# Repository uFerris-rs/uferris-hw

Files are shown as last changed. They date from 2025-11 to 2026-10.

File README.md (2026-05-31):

# 🦀 uFerris Embedded Rust Learner Board

<div align="center">
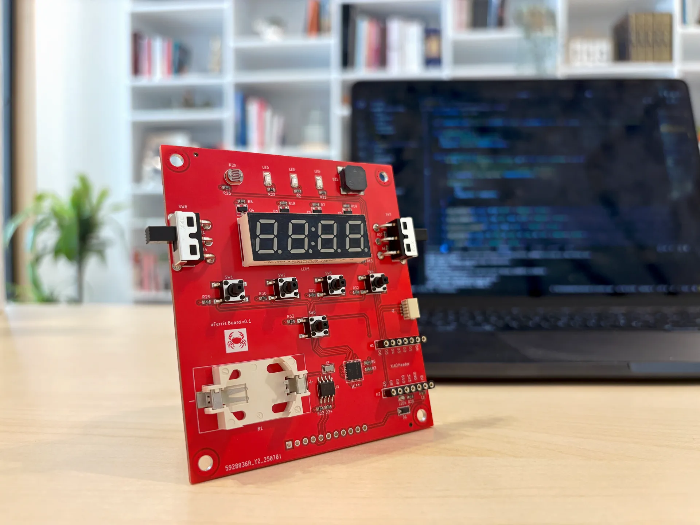
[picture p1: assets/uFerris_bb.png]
  
</div>
<br>

**uFerris** is a versatile, all-in-one learner board designed to:

- Support multiple controllers on a single reference platform.
- Enable programming of standard peripherals (GPIO, Timers/Counters, Analog, PWM, Serial Comms).
- Allow learners to build a complete embedded product replica.
- Serve as a centralized reference for Rust embedded beginners.

## 📦 Purchase

For pre-built hardware, uFerris can be acquired from [The Embedded Rustacean Store](https://shop.theembeddedrustacean.com/).

## 🧱 Board Variants

### Megalops Baseboard
The baseboard is equipped with components that let you practice and apply your skills across all standard peripherals. The baseboard also features a SeeedStudio XIAO platform header, giving the flexibility to work with a wide range of controllers.

<div align="center">
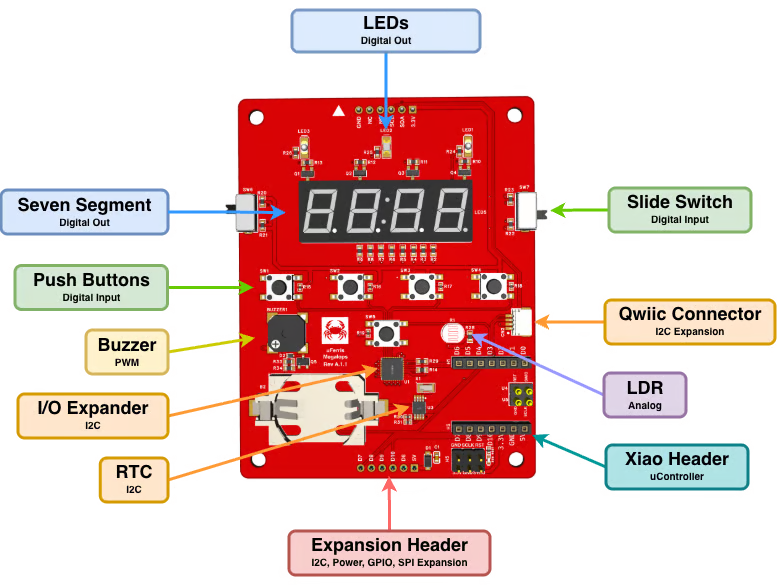
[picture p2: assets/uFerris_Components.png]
  
</div>
<br>

<div align="center">
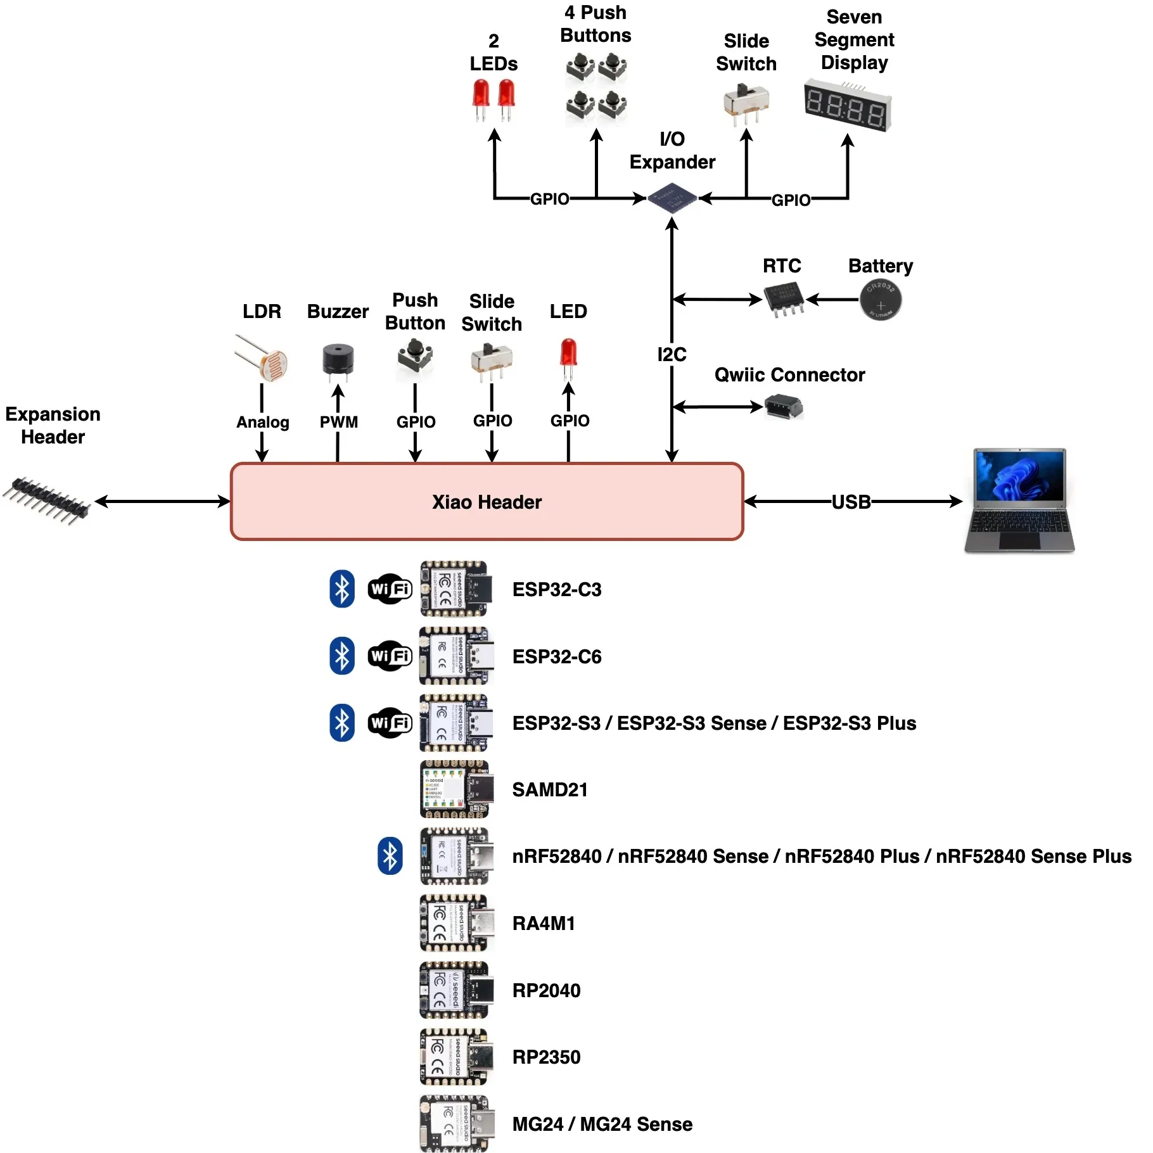
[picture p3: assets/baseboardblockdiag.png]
  
</div>
<br>

### Megalops Power Expansion Board

The Power Expansion Board lets the uFerris baseboard run independently of USB power. It features a 2×AAA battery holder with a current measurement circuit, making it easy to measure current consumption for your projects. It also includes an SD card holder—perfect for learning SPI and storing or logging data directly from your applications.

<div align="center">
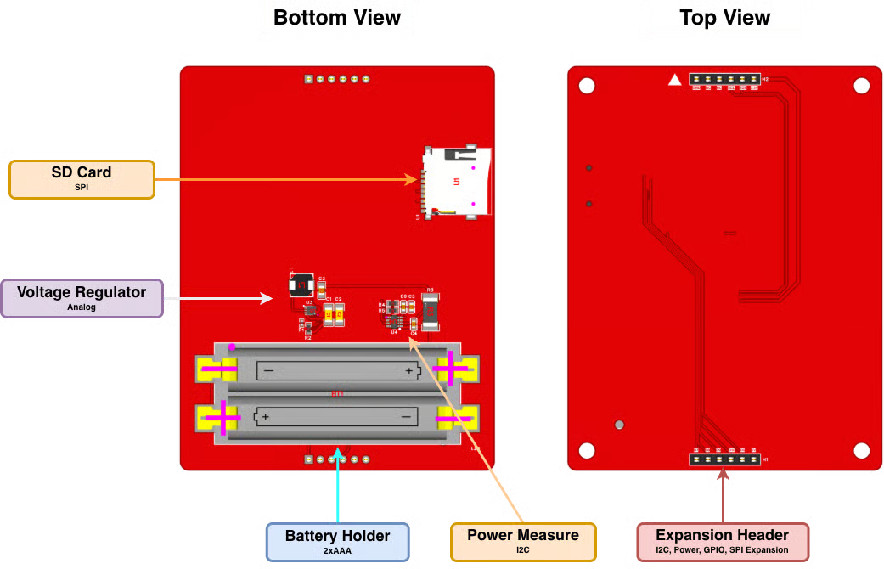
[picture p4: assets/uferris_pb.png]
  
</div>
<br>

## 📁 Repository Structure
- [`boards/`](boards/) → Hardware designs (schematic, PCB, BOM)
- [`docs/`](docs/) → Documentation and certifications
- [`firmware/`](firmware/) → Example Rust firmware projects
- [`assets/`](assets/) → Images and media assets

## 🏁 Getting Started
To get started, refer to the [getting-started.md](https://github.com/uFerris-rs/uferris-hw/blob/main/docs/getting-started.md) document.

## 📄 Certifications

uFerris is certified open source hardware by the Open Source Hardware Association.

<div align="center">
<a href="https://certification.oshwa.org/jo000001.html">
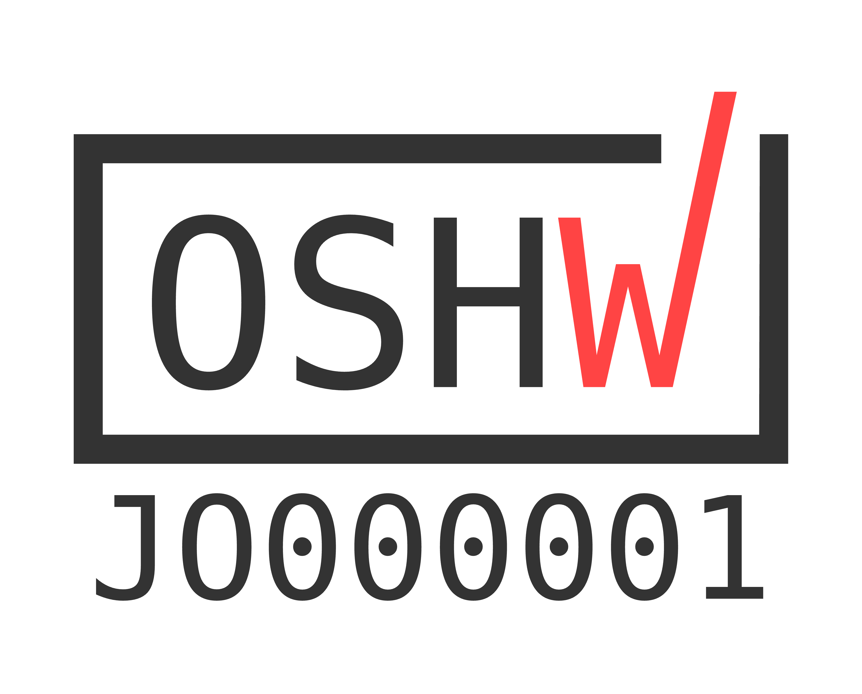
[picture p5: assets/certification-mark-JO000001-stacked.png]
OSHW Certified JO000001
  
</a>
</div>

- **OSHWA UID:** [JO000001](https://certification.oshwa.org/jo000001.html)
- **Certification Date:** May 8, 2026
- **Hardware License:** CC-BY-SA-4.0
- **Software License:** MIT

uFerris is the first OSHWA-certified project from Jordan.

See [`docs/`](docs/) for more compliance details.

## 📜 License

All uFerris boards and their derivatives are licensed
under the Creative Commons Attribution-ShareAlike 4.0 International License (CC BY-SA 4.0).

All software and firmware examples are licensed under the MIT License.

## 🌐 Learn More

To stay updated and learn more about uFerris, subscribe to The Embedded Rustacean newsletter: https://www.theembeddedrustacean.com/subscribe 

---

Developed and maintained by **The Embedded Rustacean**  🦀

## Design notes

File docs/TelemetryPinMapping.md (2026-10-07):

# uFerris Megalops Telemetry Board Pin Mapping

The telemetry board (Rev A.0.0) carries an RP2040 that reads and drives the uFerris baseboard lines. It mates with the baseboard's Telemetry Headers (U2, U6, U7) and Expansion Headers (H3, H4).

`Signal` columns use the baseboard net names (see `uFerrisPinMapping.md`), so names are identical across both boards. Where the telemetry schematic uses a different net name, it is shown in `Telemetry Net`.

Eight baseboard signals share four RP2040 pins each through two TMUX1574 2:1 muxes (U4, U9), switched by `MODESEL` (GPIO0). With `MODESEL = 0` the RP2040 sees the XIAO-side signals; with `MODESEL = 1` it sees the 7-segment signals. Both mux enables (EN#) are tied to GND.

## RP2040 GPIO Map

| RP2040 GPIO | RP2040 Pin | Function | Telemetry Net | Path | Signal (MODESEL=0) | Signal (MODESEL=1) | Telemetry Header Pin | Baseboard Header Pin | Baseboard Source | Notes |
|:---|:---|:---|:---|:---|:---|:---|:---|:---|:---|:---|
| GPIO0 | 2 | GPIO0 | MODESEL | Mux select | - | - | - | - | - | Drives SEL on U4 and U9. 0 = XIAO-side signals, 1 = 7-segment signals |
| GPIO1 | 3 | GPIO1 | XIAOMOSI/E | Mux U9 D1 | XIAOMOSI | E | H2-3 / H5-8 | H3-3 / U6-6 | Xiao D10 / Expander P24 | |
| GPIO2 | 4 | GPIO2 | SWCLK_XIAO | Direct | SWCLK | SWCLK | H5-5 | U6-1 | Xiao SWD pad (pogo) | Net name differs from baseboard (SWCLK) |
| GPIO3 | 5 | GPIO3 | SWIO_XIAO | Direct | SWIO | SWIO | H5-3 | U6-5 | Xiao SWD pad (pogo) | Net name differs from baseboard (SWIO) |
| GPIO4 | 6 | GPIO4 | XIAORX/B | Mux U9 D2 | XIAORX | B | H2-6 / H5-2 | H3-6 / U6-7 | Xiao D7 / Expander P21 | |
| GPIO5 | 7 | GPIO5 | XIAOMISO/DP | Mux U9 D3 | XIAOMISO | DP | H2-4 / H6-1 | H3-4 / U7-9 | Xiao D9 / Expander P26 | |
| GPIO6 | 8 | GPIO6 | XIAOTX/G | Mux U9 D4 | XIAOTX | G | H2-2 / H6-9 | H3-2 / U7-8 | Xiao D6 / Expander P27 | |
| GPIO7 | 9 | GPIO7 | BUZZERWIRE/A  | Mux U4 D1 | BUZZERWIRE | A | H5-6 / H5-1 | U6-2 / U6-9 | Xiao D2/A2 / Expander P20 | |
| GPIO8 | 11 | GPIO8 | LED1WIRE/F | Mux U4 D2 | LED1WIRE | F | H6-2 / H5-7 | U7-7 / U6-4 | Xiao D1/A1 / Expander P25 | |
| GPIO9 | 12 | GPIO9 | SW5WIRE/D | Mux U4 D3 | SW5WIRE | D | H6-4 / H5-9 | U7-3 / U6-8 | Xiao D3 / Expander P23 | |
| GPIO10 | 13 | GPIO10 | XIAOSCL/C | Mux U4 D4 | XIAOSCL | C | H2-5 / H5-10 | H3-5 / U6-10 | Xiao D8 / Expander P22 | |
| GPIO11 | 14 | GPIO11 | RST_XIAO | Direct | RST | RST | H5-4 | U6-3 | Xiao SWD pad (pogo) | Net name differs from baseboard (RST) |
| GPIO12 | 15 | GPIO12 | SCL | Direct | SCL | SCL | H3-3 | H4-3 | Xiao D5 | |
| GPIO13 | 16 | GPIO13 | SDA | Direct | SDA | SDA | H3-2 | H4-2 | Xiao D4 | |
| GPIO14 | 17 | GPIO14 | SW1WIRE | Direct | SW1WIRE | SW1WIRE | H4-2 | U2-7 | Expander P07 | |
| GPIO15 | 18 | GPIO15 | SW2WIRE | Direct | SW2WIRE | SW2WIRE | H6-10 | U7-10 | Expander P06 | |
| GPIO16 | 27 | GPIO16 | SW3WIRE | Direct | SW3WIRE | SW3WIRE | H6-8 | U7-6 | Expander P05 | |
| GPIO17 | 28 | GPIO17 | SW4WIRE | Direct | SW4WIRE | SW4WIRE | H6-5 | U7-1 | Expander P04 | |
| GPIO18 | 29 | GPIO18 | LSWITCH | Direct | LSWITCH | LSWITCH | H4-5 | U2-1 | Expander P16 | |
| GPIO19 | 30 | GPIO19 | RSWITCH | Direct | RSWITCH | RSWITCH | H6-6 | U7-2 | Expander P01 | |
| GPIO20 | 31 | GPIO20 | DIGIT1 | Direct | DIGIT1 | DIGIT1 | H4-3 | U2-5 | Expander P10 | |
| GPIO21 | 32 | GPIO21 | DIGIT2 | Direct | DIGIT2 | DIGIT2 | H4-10 | U2-10 | Expander P11 | |
| GPIO22 | 34 | GPIO22 | DIGIT3 | Direct | DIGIT3 | DIGIT3 | H4-9 | U2-8 | Expander P12 | |
| GPIO23 | 35 | GPIO23 | DIGIT4 | Direct | DIGIT4 | DIGIT4 | H4-7 | U2-4 | Expander P13 | |
| GPIO24 | 36 | GPIO24 | LED2WIRE | Direct | LED2WIRE | LED2WIRE | H4-8 | U2-6 | Expander P14 | |
| GPIO25 | 37 | GPIO25 | LED3WIRE | Direct | LED3WIRE | LED3WIRE | H4-6 | U2-2 | Expander P15 | |
| GPIO26 | 38 | GPIO26 / ADC0 | LDRWIREBUF | Buffer U5 (MCP6002 follower) | LDRWIRE | LDRWIRE | H6-3 | U7-5 | Xiao D0/A0 | Analog: unity-gain buffered into ADC |
| GPIO27 | 39 | GPIO27 / ADC1 | XIAO3V3BUF | Buffer U5 (MCP6002 follower) | VCC | VCC | H3-1 | H4-1 | Baseboard 3V3 | Analog: unity-gain buffered into ADC. Net name differs from baseboard (VCC) |
| GPIO28 | 40 | GPIO28 / ADC2 | NC | - | - | - | - | - | - | Unused |
| GPIO29 | 41 | GPIO29 / ADC3 | NC | - | - | - | - | - | - | Unused |

## Header Mating

The 2×5 headers use different pin numbering on each board: the baseboard numbers odd/even across the rows, while the telemetry board numbers 1–5 down one column and 6–10 back up the other. The table gives the pin-to-pin correspondence, checked net-by-net against both netlists.

| Telemetry Header | Pin | Telemetry Net | Mates With (Baseboard) | Baseboard Signal (Net) |
|:---|:----|:---|:---|:---|
| H4 | 1 | NC | U2-9 | NC |
| H4 | 2 | SW1WIRE | U2-7 | SW1WIRE |
| H4 | 3 | DIGIT1 | U2-5 | DIGIT1 |
| H4 | 4 | NC | U2-3 | NC |
| H4 | 5 | LSWITCH | U2-1 | LSWITCH |
| H4 | 6 | LED3WIRE | U2-2 | LED3WIRE |
| H4 | 7 | DIGIT4 | U2-4 | DIGIT4 |
| H4 | 8 | LED2WIRE | U2-6 | LED2WIRE |
| H4 | 9 | DIGIT3 | U2-8 | DIGIT3 |
| H4 | 10  | DIGIT2 | U2-10 | DIGIT2 |
| H5 | 1 | A | U6-9 | A |
| H5 | 2 | B | U6-7 | B |
| H5 | 3 | SWIO_XIAO | U6-5 | SWIO |
| H5 | 4 | RST_XIAO | U6-3 | RST |
| H5 | 5 | SWCLK_XIAO | U6-1 | SWCLK |
| H5 | 6 | BUZZERWIRE | U6-2 | BUZZERWIRE |
| H5 | 7 | F | U6-4 | F |
| H5 | 8 | E | U6-6 | E |
| H5 | 9 | D | U6-8 | D |
| H5 | 10  | C | U6-10 | C |
| H6 | 1 | DP | U7-9 | DP |
| H6 | 2 | LED1WIRE | U7-7 | LED1WIRE |
| H6 | 3 | LDRWIRE | U7-5 | LDRWIRE |
| H6 | 4 | SW5WIRE | U7-3 | SW5WIRE |
| H6 | 5 | SW4WIRE | U7-1 | SW4WIRE |
| H6 | 6 | RSWITCH | U7-2 | RSWITCH |
| H6 | 7 | NC | U7-4 | NC |
| H6 | 8 | SW3WIRE | U7-6 | SW3WIRE |
| H6 | 9 | G | U7-8 | G |
| H6 | 10  | SW2WIRE | U7-10 | SW2WIRE |
| H2 | 1 | NC | H3-1 | +5V |
| H2 | 2 | XIAOTX | H3-2 | XIAOTX |
| H2 | 3 | XIAOMOSI | H3-3 | XIAOMOSI |
| H2 | 4 | XIAOMISO | H3-4 | XIAOMISO |
| H2 | 5 | XIAOSCL | H3-5 | XIAOSCL |
| H2 | 6 | XIAORX | H3-6 | XIAORX |
| H3 | 1 | XIAO3V3 | H4-1 | VCC |
| H3 | 2 | SDA | H4-2 | SDA |
| H3 | 3 | SCL | H4-3 | SCL |
| H3 | 4 | NC | H4-4 | NC |
| H3 | 5 | NC | H4-5 | NC |
| H3 | 6 | GND | H4-6 | GND |

## Other Connectors

| Connector | Pin | Net | Function |
|:---|:----|:---|:---|
| H1 (SWD, RP2040 debug) | 1 | VCC | Telemetry 3V3 |
| H1 (SWD, RP2040 debug) | 2 | SWCLK | RP2040 SWCLK (pin 24) |
| H1 (SWD, RP2040 debug) | 3 | SWD | RP2040 SWDIO (pin 25) |
| H1 (SWD, RP2040 debug) | 4 | GND | - |
| SW1 | - | RUN | RP2040 RUN (pin 26), reset button |
| SW3 | - | QSPI_SS | BOOTSEL button (via R3 1k) |
| USB1 | - | USB_D+ / USB_D- | RP2040 USB_DP/DM (pins 47/46) via 27Ω |
| USB1 | - | VUSB | AMS1117-3.3 input → telemetry VCC |
| LED1 | - | VCC | Power LED (470Ω) |

## Notes
- **Hardware peripherals don't line up with the routed pins; plan on PIO for bus capture.**
  - I²C: SCL is on GPIO12 and SDA on GPIO13. In the RP2040's fixed I²C mapping GPIO12 is I2C0 SDA and GPIO13 is I2C0 SCL, so the pair is swapped for the hardware block.
  - UART: XIAOTX lands on GPIO6, which has no UART RX function. XIAORX is on GPIO4 (UART1 TX), so the RP2040 can drive the XIAO's RX with hardware UART but can't receive the XIAO's TX that way.
  - SPI: XIAOMOSI (GPIO1), XIAOMISO (GPIO5) and XIAOSCL (GPIO10) don't form a hardware SPI set.
- XIAO serial/SPI lines and the 7-segment lines are never visible at the same time; see `MODESEL`.
- `XIAO3V3` is the baseboard `VCC` rail (H4-1), buffered into ADC1 for supply monitoring. The telemetry board's own `VCC` is a separate 3V3 from USB; the boards share only GND (H4-6).
- Baseboard H3-1 (+5V) is not connected on the telemetry side.
- GPIO28 and GPIO29 are unused.
- The telemetry net names `SWCLK` and `SWD` belong to the RP2040's own debug port (H1), **not** the baseboard XIAO SWD lines (`SWCLK_XIAO`, `SWIO_XIAO`, `RST_XIAO`).

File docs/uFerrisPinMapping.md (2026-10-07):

# uFerris Pin Mapping

The table below provides a comprehensive mapping of the various components and their connections to the Xiao, I/O Expander, Expansion Headers H3/H4, Telemetry Headers U2/U6/U7, the SWD debug header H5 and pogo pins U4/U5, and the ESP32-C3 and ESP32-C6 pins.

Note that the enclosure labels are in refrence to the 3D printed enclosure for the uFerris alarm clock project.

`Signal (Net)` is the schematic net name and is the canonical signal name shared with the telemetry extension board. Header pins are written as `<RefDes>-<Pin>`.

| Enclosure Label | Component Connection | Signal (Net) | Xiao Pin | I/O Expander Pin | Header H3 Pin | Header H4 Pin | Telemetry Header Pin | Debug H5 Pin | SWD Pogo Pin | Direction | ESP32-C3 Pin | ESP32-C6 Pin |
|:---|:---|:---|:---|:---|:---|:---|:---|:---|:---|:---|:---|:---|
| Alarm | LED 1 | LED1WIRE | D1/A1 | - | - | - | U7-7 | - | - | Output | GPIO3 | GPIO1 |
| LED | LED 2 | LED2WIRE | - | P14 | - | - | U2-6 | - | - | Output | - | - |
| PM | LED 3 | LED3WIRE | - | P15 | - | - | U2-2 | - | - | Output | - | - |
| - | Buzzer | BUZZERWIRE | D2/A2 | - | - | - | U6-2 | - | - | Output | GPIO4 | GPIO2 |
| Hour | SW1 | SW1WIRE | - | P07 | - | - | U2-7 | - | - | Input | - | - |
| Minute | SW2 | SW2WIRE | - | P06 | - | - | U7-10 | - | - | Input | - | - |
| Time | SW3 | SW3WIRE | - | P05 | - | - | U7-6 | - | - | Input | - | - |
| Alarm | SW4 | SW4WIRE | - | P04 | - | - | U7-1 | - | - | Input | - | - |
| Snooze | SW5 | SW5WIRE | D3 | - | - | - | U7-3 | - | - | Input | GPIO5 | GPIO21 |
| 12/24 | SW6 | LSWITCH | - | P16 | - | - | U2-1 | - | - | Input | - | - |
| On/Off | SW7 | RSWITCH | - | P01 | - | - | U7-2 | - | - | Input | - | - |
| - | SDA | SDA | D4 | - | - | P2 | - | - | - | Comms | GPIO6 | GPIO22 |
| - | SCL | SCL | D5 | - | - | P3 | - | - | - | Comms | GPIO7 | GPIO23 |
| - | LDR | LDRWIRE | D0/A0 | - | - | - | U7-5 | - | - | Analog | GPIO2 | GPIO0 |
| - | Digit 1 | DIGIT1 | - | P10 | - | - | U2-5 | - | - | Output | - | - |
| - | Digit 2 | DIGIT2 | - | P11 | - | - | U2-10 | - | - | Output | - | - |
| - | Digit 3 | DIGIT3 | - | P12 | - | - | U2-8 | - | - | Output | - | - |
| - | Digit 4 | DIGIT4 | - | P13 | - | - | U2-4 | - | - | Output | - | - |
| - | Seg A | A | - | P20 | - | - | U6-9 | - | - | Output | - | - |
| - | Seg B | B | - | P21 | - | - | U6-7 | - | - | Output | - | - |
| - | Seg C | C | - | P22 | - | - | U6-10 | - | - | Output | - | - |
| - | Seg D | D | - | P23 | - | - | U6-8 | - | - | Output | - | - |
| - | Seg E | E | - | P24 | - | - | U6-6 | - | - | Output | - | - |
| - | Seg F | F | - | P25 | - | - | U6-4 | - | - | Output | - | - |
| - | Seg G | G | - | P27 | - | - | U7-8 | - | - | Output | - | - |
| - | DP | DP | - | P26 | - | - | U7-9 | - | - | Output | - | - |
| - | XiaoTx | XIAOTX | D6 | nINT | P2 | - | - | - | - | - | GPIO21 | GPIO16 |
| - | XiaoMosi | XIAOMOSI | D10 | - | P3 | - | - | - | - | - | GPIO10 | GPIO18 |
| - | XiaoMiso | XIAOMISO | D9 | - | P4 | - | - | - | - | - | GPIO9 | GPIO20 |
| - | XiaoScl | XIAOSCL | D8 | - | P5 | - | - | - | - | - | GPIO8 | GPIO19 |
| - | XiaoRx | XIAORX | D7 | - | P6 | - | - | - | - | - | GPIO20 | GPIO17 |
| - | SWCLK | SWCLK | SWD pad (pogo) | - | - | - | U6-1 | H5-4 | U5-2 | Debug | - | - |
| - | SWDIO | SWIO | SWD pad (pogo) | - | - | - | U6-5 | H5-5 | U4-2 | Debug | - | - |
| - | RST | RST | SWD pad (pogo) | - | - | - | U6-3 | H5-6 | U4-1 | Debug | - | - |

## Header Pinouts

Pin-ordered view of the telemetry and debug headers (schematic Rev A.2.0). `NC` = not connected.

### Telemetry Headers (U2, U6, U7 — PZ254-2-05-S, 2×5, 2.54 mm)

**U2**

| Pin | Signal (Net) | Component | Source |
|:----|:---|:---|:---|
| 1 | LSWITCH | SW6 | Expander P16 |
| 2 | LED3WIRE | LED 3 | Expander P15 |
| 3 | NC | - | - |
| 4 | DIGIT4 | Digit 4 | Expander P13 |
| 5 | DIGIT1 | Digit 1 | Expander P10 |
| 6 | LED2WIRE | LED 2 | Expander P14 |
| 7 | SW1WIRE | SW1 | Expander P07 |
| 8 | DIGIT3 | Digit 3 | Expander P12 |
| 9 | NC | - | - |
| 10  | DIGIT2 | Digit 2 | Expander P11 |

**U6**

| Pin | Signal (Net) | Component | Source |
|:----|:---|:---|:---|
| 1 | SWCLK | SWCLK | Xiao SWD pad (pogo) |
| 2 | BUZZERWIRE | Buzzer | Xiao D2/A2 |
| 3 | RST | RST | Xiao SWD pad (pogo) |
| 4 | F | Seg F | Expander P25 |
| 5 | SWIO | SWDIO | Xiao SWD pad (pogo) |
| 6 | E | Seg E | Expander P24 |
| 7 | B | Seg B | Expander P21 |
| 8 | D | Seg D | Expander P23 |
| 9 | A | Seg A | Expander P20 |
| 10  | C | Seg C | Expander P22 |

**U7**

| Pin | Signal (Net) | Component | Source |
|:----|:---|:---|:---|
| 1 | SW4WIRE | SW4 | Expander P04 |
| 2 | RSWITCH | SW7 | Expander P01 |
| 3 | SW5WIRE | SW5 | Xiao D3 |
| 4 | NC | - | - |
| 5 | LDRWIRE | LDR | Xiao D0/A0 |
| 6 | SW3WIRE | SW3 | Expander P05 |
| 7 | LED1WIRE | LED 1 | Xiao D1/A1 |
| 8 | G | Seg G | Expander P27 |
| 9 | DP | DP | Expander P26 |
| 10  | SW2WIRE | SW2 | Expander P06 |

### SWD Debug Header (H5 — PH2.54-2X3P, 2×3, 2.54 mm)

**H5**

| Pin | Signal (Net) | Component | Source |
|:----|:---|:---|:---|
| 1 | VCC | Power | - |
| 2 | GND | Power | - |
| 3 | GND | Power | - |
| 4 | SWCLK | SWCLK | Xiao SWD pad (pogo) |
| 5 | SWIO | SWDIO | Xiao SWD pad (pogo) |
| 6 | RST | RST | Xiao SWD pad (pogo) |

### SWD Pogo Pins (U4, U5 — 2-pin pogo, 2.50 mm)
These contact the SWD pads on the underside of XIAO variants that expose them.

**U4**

| Pin | Signal (Net) | Component | Source |
|:----|:---|:---|:---|
| 1 | RST | RST | Xiao SWD pad (pogo) |
| 2 | SWIO | SWDIO | Xiao SWD pad (pogo) |

**U5**

| Pin | Signal (Net) | Component | Source |
|:----|:---|:---|:---|
| 1 | GND | Power | - |
| 2 | SWCLK | SWCLK | Xiao SWD pad (pogo) |

### Notes
- The telemetry board also mates with Expansion Headers H3 and H4, which supply power/GND, SDA/SCL and the XIAO serial/SPI lines (XIAOTX, XIAORX, XIAOMOSI, XIAOMISO, XIAOSCL).
- SWCLK, SWIO and RST are shared between U6, H5 and the pogo pins.

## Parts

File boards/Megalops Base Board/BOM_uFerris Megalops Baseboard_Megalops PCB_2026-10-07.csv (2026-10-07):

No. | Quantity | Comment | Designator | Footprint | Value | Manufacturer Part | Manufacturer | Supplier Part | Supplier
1 | 1 | CR2032-BS-6-1 | B2 | BAT-TH_CR2032-BS-6-1 |  | CR2032-BS-6-1 | QIJEY | C70377 | LCSC
2 | 1 | 2.7kHz | BUZZER1 | BUZ-SMD_4P-L8.5-W8.5-P8.50-BR | 2.7kHz | MLT-8530 | 华能 | C94599 | LCSC
3 | 1 | 10uF | C1 | C0603 | 10uF | CL10A106KP8NNNC | SAMSUNG(三星) | C19702 | LCSC
4 | 1 | XY-SM04B-SRSS-TB | CN2 | CONN-SMD_4P-P1.00_XY-SM04B-SRSS-TB |  | XY-SM04B-SRSS-TB | XYECONN(辛译) | C51940130 | LCSC
5 | 1 | MBR0520LT1G | D1 | SOD-123_L2.8-W1.8-LS3.7-RD |  | MBR0520LT1G | onsemi(安森美) | C23848 | LCSC
6 | 1 | 1N4148WT | D2 | SOD-523_L1.2-W0.8-LS1.6-RD |  | 1N4148WT | luJing(鲁晶) | C53058795 | LCSC
7 | 2 | HC-PM254-5.0H-1x7PZ | H1,H2 | HDR-TH_7P-P2.54-V-M-3 |  | HC-PM254-5.0H-1x7PZ | HC(虹成电子) | C27985232 | LCSC
8 | 1 | PH2.54-06PB2G-H25 | H3 | HDR-TH_6P-P2.54-V-M_BLUE |  | PH2.54-06PB2G-H25 | JXTCONN(聚兴泰) | C42431807 | LCSC
9 | 1 | PZ254V-11-06P-YL | H4 | HDR-TH_6P-P2.54-V-M |  | PZ254V-11-06P-YL | XFCN(兴飞) | C41425309 | LCSC
10 | 1 | PH2.54-2X3P-H25 | H5 | HDR-TH_6P-P2.54-V-M-R2-C3-S2.54-1 |  | PH2.54-2X3P-H25 | JXTCONN(聚兴泰) | C42431837 | LCSC
11 | 1 | YLED1206R | LED1 | LED1206-FD |  | YLED1206R | YONGYUTAI(永裕泰) | C28310439 | LCSC
12 | 1 | YLED1206B | LED2 | LED1206-FD_BULE |  | YLED1206B | YONGYUTAI(永裕泰) | C28310438 | LCSC
13 | 1 | YLED1206Y | LED3 | LED1206-FD |  | YLED1206Y | YONGYUTAI(永裕泰) | C30584802 | LCSC
14 | 1 | SZYY0402R | LED4 | LED0402-RD_RED |  | SZYY0402R | yongyu(永裕光电) | C434445 | LCSC
15 | 1 | SLR0394DRC5BD | LED5 | LED-SEG-TH_SLR0394DRC5BD |  | SLR0394DRC5BD | SUNLIGHT(光华) | C225902 | LCSC
16 | 4 | BC847C | Q1,Q2,Q3,Q4 | SOT-23-3_L2.9-W1.3-P1.90-LS2.4-BR |  | BC847C | R+O(宏嘉诚) | C7420337 | LCSC
17 | 1 | S9013 | Q5 | SOT-23-3_L3.0-W1.7-P0.95-LS2.9-BR |  | S9013 | CCX(晁禾) | C53373689 | LCSC
18 | 1 | GL5528 | R1 | RES-TH_L5.1-W4.3-P3.40-D0.5 |  | GL5528 | 森霸 | C125627 | LCSC
19 | 8 | 330Ω | R2,R3,R4,R5,R6,R7,R8,R9 | R0603 | 330Ω | SCR0603F330R | VO(翔胜) | C3016255 | LCSC
20 | 5 | 1kΩ | R10,R11,R12,R13,R34 | R0603 | 1kΩ | 0603WAF1001T5E | UNI-ROYAL(厚声) | C21190 | LCSC
21 | 3 | 10kΩ | R14,R28,R33 | R0603 | 10kΩ | 0603WAF1002T5E | UNI-ROYAL(厚声) | C25804 | LCSC
22 | 7 | 4.7kΩ | R15,R16,R17,R18,R19,R30,R31 | R0402 | 4.7kΩ | FRC0402J472 TS | FOJAN(富捷) | C2906941 | LCSC
23 | 4 | 4.7kΩ | R20,R21,R22,R23 | R0603 | 4.7kΩ | FRC0603J472 TS | FOJAN(富捷) | C2907166 | LCSC
24 | 3 | 120Ω | R24,R25,R26 | R0603 | 120Ω | FRC0603J121 TS | FOJAN(富捷) | C2907096 | LCSC
25 | 1 | 0Ω | R29 | R0603 | 0Ω | 0603WAF0000T5E | UNI-ROYAL(厚声) | C21189 | LCSC
26 | 1 | 220Ω | R32 | R0402 | 220Ω | RC0402FR-07220RL | YAGEO(国巨) | C112291 | LCSC
27 | 5 | UK-B0219-TP-160 | SW1,SW2,SW3,SW4,SW5 | SW-SMD_4P-L6.0-W6.0-P4.50-LS8.5 |  | UK-B0219-TP-160 | USAKRO(美韩) | C780500 | LCSC
28 | 2 | SK-12E12-G5 | SW6,SW7 | SW-TH_SK-12E12-G5 |  | SK-12E12-G5 | 韩国韩荣 | C136720 | LCSC
29 | 1 | TCA6424ARGJR | U1 | VQFN-32_L5.0-W5.0-P0.50-TL-EP |  | TCA6424ARGJR | TI(德州仪器) | C80692 | LCSC
30 | 3 | PZ254-2-05-S | U2,U6,U7 | HDR-SMD_10P-P2.54-V-M-R2-C5-LS7.5 |  | PZ254-2-05-S | HCTL(华灿天禄) | C3294463 | LCSC
31 | 1 | DS1338U-3+T&R | U3 | UMAX-8_L3.0-W3.0-P0.65-LS4.9-BL-1 |  | DS1338U-3+T&R | ADI(亚德诺)/MAXIM(美信) | C709722 | LCSC
32 | 2 | YZ215215105P-02025-01 | U4,U5 | POGO-TH_2P-P2.50-YZ215215105P-02025-01 |  | YZ215215105P-02025-01 | Xinyangze(鑫扬泽) | C5200673 | LCSC
33 | 1 | 32.768kHz | X1 | OSC-SMD_2P-L3.2-W1.5 | 32.768kHz | ABS07-32.768KHZ-T | ABRACON | C130253 | LCSC

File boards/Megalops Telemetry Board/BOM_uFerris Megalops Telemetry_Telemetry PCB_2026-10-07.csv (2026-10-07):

No. | Quantity | Comment | Designator | Footprint | Value | Manufacturer Part | Manufacturer | Supplier Part | Supplier
1 | 9 | 100nF | C1,C2,C3,C4,C5,C6,C7,C8,C10 | C0603 | 100nF | 0603X7R104K250NT | AIDE(爱迪电容) | C48579280 | LCSC
2 | 2 | 10uF | C9,C11 | C0603 | 10uF | FCC0603X106M250CT | FOJAN(富捷) | C7467055 | LCSC
3 | 3 | 100nF | C12,C13,C14 | C0603 | 100nF
4 | 2 | 1uF | C15,C16 | C0603 | 1uF | CL10A105KO8NNNC | SAMSUNG(三星) | C1592 | LCSC
5 | 2 | 15pF | C17,C18 | C0402 | 15pF | CC0402JRNPO9BN150 | YAGEO(国巨) | C106997 | LCSC
6 | 1 | PZ254R-11-04P | H1 | HDR-TH_4P-P2.54-H-M-W10.4 |  | PZ254R-11-04P | XFCN(兴飞) | C492412 | LCSC
7 | 2 | PM254V-11-06-H85 | H2,H3 | HDR-TH_6P-P2.54-V-F |  | PM254V-11-06-H85 | XFCN(兴飞) | C2832269 | LCSC
8 | 3 | PM254-2-05-S-8.5 | H4,H5,H6 | HDR-SMD_10P-P2.54-V-F-R2-C5-LS7.1-1 |  | PM254-2-05-S-8.5 | HCTL(华灿天禄) | C3975150 | LCSC
9 | 1 | XL-1005SURC | LED1 | LED0402-RD |  | XL-1005SURC | XINGLIGHT(成兴光) | C25503345 | LCSC
10 | 2 | 27Ω | R1,R2 | R0402 | 27Ω | 0402WGF270JTCE | UNI-ROYAL(厚声) | C25100 | LCSC
11 | 2 | 1K | R3,R4 | R0603 | 1K
12 | 1 | 1kΩ | R5 | R0402 | 1kΩ | FRC0402F1001TS | FOJAN(富捷) | C2906864 | LCSC
13 | 2 | 5.1kΩ | R6,R7 | R0402 | 5.1kΩ | FRC0402J512 TS | FOJAN(富捷) | C2906948 | LCSC
14 | 1 | 470Ω | R8 | R0402 | 470Ω | FRC0402J471 TS | FOJAN(富捷) | C2906945 | LCSC
15 | 2 | TS4538B3J | SW1,SW3 | SW-TH_TS4538B3J |  | TS4538B3J | SHOU HAN(首韩) | C2681490 | LCSC
16 | 1 | RP2040 | U1 | LQFN-56_L7.0-W7.0-P0.4-EP |  | RP2040 | Raspberry Pi(树莓派) | C2040 | LCSC
17 | 1 | AMS1117-3.3 | U3 | SOT-223-3_L6.5-W3.4-P2.30-LS7.0-BR |  | AMS1117-3.3 | Advanced Monolithic Systems | C6186 | LCSC
18 | 2 | TMUX1574PWR | U4,U9 | TSSOP-16_L5.0-W4.4-P0.65-LS6.4-BL |  | TMUX1574PWR | TI(德州仪器) | C2673443 | LCSC
19 | 1 | MCP6002DRG | U5 | SOP-8_L4.9-W3.9-P1.27-LS6.0-BL |  | MCP6002DRG | HGC(深圳汉芯) | C5145244 | LCSC
20 | 1 | W25Q128JVSIQ | U8 | SOIC-8_L5.3-W5.3-P1.27-LS8.0-BL |  | W25Q128JVSIQ | Winbond(华邦) | C113767 | LCSC
21 | 1 | USB4105-GF-A-120 | USB1 | USB-C-SMD_MC-311D |  | USB4105-GF-A-120 | GCT | C5184243 | LCSC
22 | 1 | 12MHz | X2 | CRYSTAL-SMD_4P-L3.2-W2.5-BL | 12MHz | TAXM12M4RFBCCT2T | YJX(雅晶鑫) | C133337 | LCSC

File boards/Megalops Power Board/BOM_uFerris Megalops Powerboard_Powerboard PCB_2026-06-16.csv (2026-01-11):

No. | Quantity | Comment | Designator | Footprint | Value | Manufacturer Part | Manufacturer | Supplier Part | Supplier
1 | 1 | BH-AAA-B5AA001 | BT1 | BAT-SMD_BH-AAA-B5AA001 |  | BH-AAA-B5AA001 | MYOUNG(美阳) | C964881 | LCSC
2 | 2 | 100nF | C4,C5 | C0603 | 100nF | TCC0603X7R104K500CT | CCTC(三环) | C282519 | LCSC
3 | 1 | 4.7uF | C6 | C0603 | 4.7uF | CL10A475KP8NNNC | SAMSUNG(三星) | C1705 | LCSC
4 | 1 | 10uF | C7 | C0805 | 10uF | CL21B106KPQNNNE | SAMSUNG(三星) | C32635 | LCSC
5 | 1 | 1nF | C8 | C0603 | 1nF | CC0603KRX7R9BB102 | YAGEO(国巨) | C100040 | LCSC
6 | 1 | 1uF | C9 | C0603 | 1uF | CL10B105KA8NNNC | SAMSUNG(三星) | C29936 | LCSC
7 | 2 | 4.7uF | C10,C11 | C0805 | 4.7uF | CL21B475KOFNNNE | SAMSUNG(三星) | C107365 | LCSC
8 | 2 | PM254V-11-06-H85 | H1,H2 | HDR-TH_6P-P2.54-V-F |  | PM254V-11-06-H85 | XFCN(兴飞) | C2832269 | LCSC
9 | 1 | 4.7uH | L1 | IND-SMD_L4.5-W4.0 | 4.7uH | CY43-4.7UH | SHOU HAN(首韩) | C2879693 | LCSC
10 | 1 | 100mΩ | R3 | RES-SMD_L6.4-W3.2-R2512 | 100mΩ | HoJLR2512-3W-100mR-1% | Milliohm(毫欧) | C2903476 | LCSC
11 | 3 | 10kΩ | R4,R5,R11 | R0603 | 10kΩ | SCR0603J10K | VO(翔胜) | C3017715 | LCSC
12 | 1 | 5.1Ω | R6 | R0603 | 5.1Ω | FRC0603F5R10TS | FOJAN(富捷) | C2907045 | LCSC
13 | 1 | 10kΩ | R7 | R0603 | 10kΩ | RC0603FR-0710KL | YAGEO(国巨) | C98220 | LCSC
14 | 1 | 31.6kΩ | R8 | R0603 | 31.6kΩ | FRC0603F3162TS | FOJAN(富捷) | C2933196 | LCSC
15 | 1 | 4.7kΩ | R9 | R0805 | 4.7kΩ | FRC0805J472 TS | FOJAN(富捷) | C2907326 | LCSC
16 | 1 | 0Ω | R10 | R0805 | 0Ω | 0805W8F0000T5E | UNI-ROYAL(厚声) | C17477 | LCSC
17 | 1 | TF-015-N | U1 | TF-SMD_TF-015 |  | TF-015-N | HanElectricity(瀚源) | C5362196 | LCSC
18 | 1 | INA219AIDCNR | U4 | SOT-23-8_L3.0-W1.7-P0.65-LS2.8-BR |  | INA219AIDCNR | TI(德州仪器) | C87469 | LCSC
19 | 1 | MP3120DJ-LF-Z | U5 | TSOT-23-6_L2.9-W1.6-P0.95-LS2.6-BL |  | MP3120DJ-LF-Z | MPS(芯源) | C69608 | LCSC

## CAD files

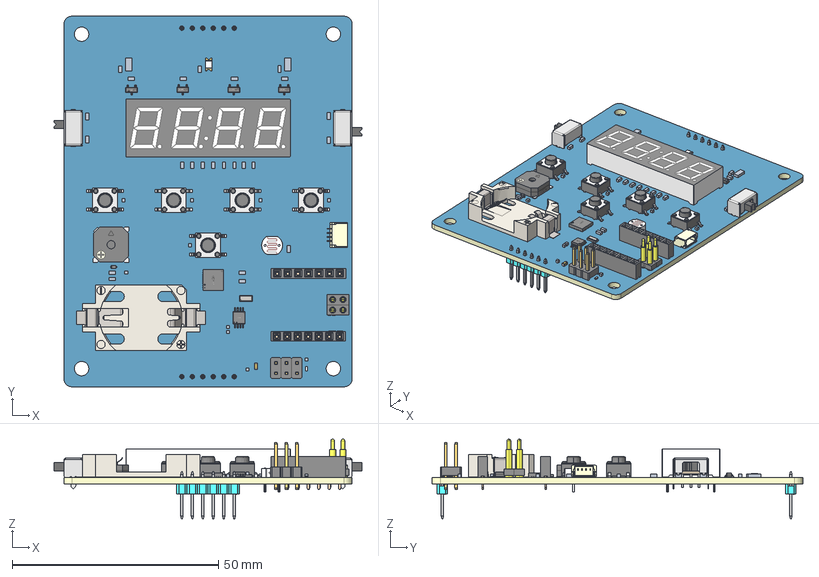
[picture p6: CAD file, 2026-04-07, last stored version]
boards/Megalops Base Board/3D_Megalops PCB_2026-04-07.step
74.7 x 90.0 x 19.4 mm
Board~OeeF
TopCopper~OeeF
BottomCopper~OeeF
TopFpcStiffener~OeeF
BottomFpcStiffener~OeeF
SOD-123_L2.8-W1.8-LS3.7-RD~SOD-123_L2.8-W1.8-LS3.7-RD~OeeF
HDR-TH_6P-P2.54-V-M_BLUE~HDR-TH_6P-P2.54-V-M_BLUE~OeeF x 2
VQFN-32_L5.0-W5.0-P0.50-TL-EP~VQFN-32_L5.0-W5.0-H1.0-P0.50~OeeF
R34~R0603~R0603~OeeF x 24
C0603~C0603_L1.6-W0.8-H0.8~OeeF
R32~R0402~R0402_L1.0-W0.5-H0.4~OeeF x 8
BAT-TH_CR2032-BS-6-1~BAT-SMD_L28.5-W16.0-H5.5-LS31.3_ CR2032-BS-6-1~OeeF
RES-TH_L5.1-W4.3-P3.40-D0.5~RES-TH_L5.1-W4.3-P3.40-D0.5~OeeF
OSC-SMD_2P-L3.2-W1.5~OSC-SMD_2P-L3.2-W1.5-H0.9~OeeF
LED3~LED1206-FD~LED1206-FD~OeeF x 2
LED0402-RD_RED~LED0402-RD_RED~OeeF
HDR-TH_6P-P2.54-V-M-R2-C3-S2.54-1~HDR2.54-M-LI-2x3P~OeeF
SOT-23-3_L2.9-W1.3-P1.90-LS2.4-BR~SOT-23-3P_ L2.9-W1.3-H1.0-LS2.4-P0.95~OeeF x 4
BUZ-SMD_4P-L8.5-W8.5-P8.50-BR~BUZ-SMD_4P-L8.5-W8.5-H3.0~OeeF
SOD-523_L1.2-W0.8-LS1.6-RD~SOD-523_L1.2-W0.8-H0.7-LS1.6~OeeF
SOT-23-3_L3.0-W1.7-P0.95-LS2.9-BR~SOT-23-3L_ L2.9-W1.6-H1.1-LS2.8-P0.95~OeeF
UMAX-8_L3.0-W3.0-P0.65-LS4.9-BL-1~UMAX-8_ L3.0-W3.0-H1.1-LS4.9-P0.65~OeeF
LED1206-FD_BULE~LED1206-FD_BULE~OeeF
SW-SMD_4P-L6.0-W6.0-P4.50-LS8.5~SW-SMD_4P-L6.0-W6.0-P4.50-LS8.5~OeeF x 5
SW-TH_SK-12D07VG6~3Pins SPDT switch SK-12D07 1P2T~OeeF x 2
CONN-SMD_4P-P1.00_ XY-SM04B-SRSS-TB~SM04B-SRSS-TB--3DModel-STEP-269445~OeeF
HDR-TH_7P-P2.54-V-M-3~HDR-TH_7P-P2.54-V-M-3~OeeF x 2
LED-SEG-TH_SLR0394DRC5BD~LED-SEG-TH_ 12P-L39.9-W14.0-H7.0-P2.54-S11.3~OeeF
POGO-TH_2P-P2.50-YZ215215105P-02025-01~POGO-TH_ 2P-P2.50-YZ215215105P-02025-01~OeeF x 2

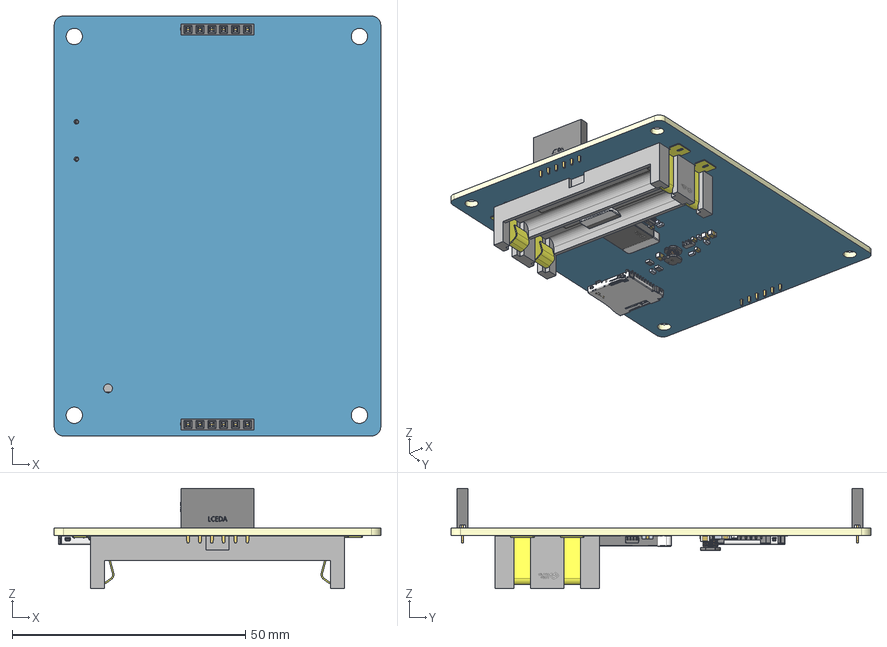
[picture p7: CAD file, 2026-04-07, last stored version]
boards/Megalops Power Board/3D_Powerboard PCB_2026-04-07.step
70.0 x 90.0 x 21.5 mm
Board~08G4
TopCopper~08G4
BottomCopper~08G4
TopFpcStiffener~08G4
BottomFpcStiffener~08G4
C0603~C0603_L1.6-W0.8-H0.8~08G4 x 5
R11~R0603~R0603~08G4 x 6
HDR-TH_6P-P2.54-V-F~HDR-TH_6P-P2.54-V-F~08G4 x 2
RES-SMD_L6.4-W3.2-R2512~RES-SMD_L6.4-W3.2-R2512~08G4
C0805~C0805_L2.0-W1.3-H1.3~08G4 x 3
R0805~R0805_L2.0-W1.3-H0.6~08G4 x 2
IND-SMD_L4.5-W4.0~IND-SMD_L4.5-W4.0-H3.2~08G4
SOT-23-8_L3.0-W1.7-P0.65-LS2.8-BR~SOT-23-8_ L2.9-W1.6-H1.5-LS2.8-P0.65~08G4
TF-SMD_TF-015~TF-SMD_L14.8-W14.5-H1.9-P1.1~08G4
TSOT-23-6_L2.9-W1.6-P0.95-LS2.6-BL~TSOT-23-6_ L2.9-W1.6-P0.95-LS2.6-BL~08G4
BAT-SMD_BH-AAA-B5AA001~BAT-SMD_BH-AAA-B5AA001~08G4

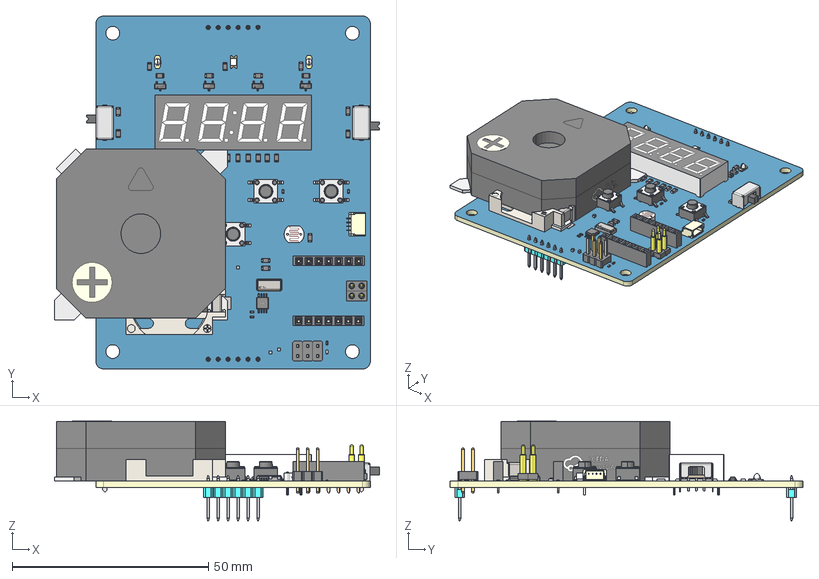
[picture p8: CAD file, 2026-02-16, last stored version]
boards/Megalops Base Board/3D_Megalops PCB_2026-02-16.step
82.9 x 90.0 x 25.4 mm
Board~X9VW
TopCopper~X9VW
BottomCopper~X9VW
TopFpcStiffener~X9VW
BottomFpcStiffener~X9VW
HDR-TH_6P-P2.54-V-M_BLUE~HDR-TH_6P-P2.54-V-M_BLUE~X9VW x 2
SOD-123_L2.8-W1.8-LS3.7-RD~SOD-123_L2.8-W1.8-LS3.7-RD~X9VW
LED0402-RD_RED~LED0402-RD_RED~X9VW
RES-TH_L5.1-W4.3-P3.40-D0.5~RES-TH_L5.1-W4.3-P3.40-D0.5~X9VW
SW-SMD_4P-L6.0-W6.0-P4.50-LS8.5~SW-SMD_4P-L6.0-W6.0-P4.50-LS8.5~X9VW x 5
OSC-SMD_2P-L3.2-W1.5~OSC-SMD_2P-L3.2-W1.5-H0.9~X9VW
UMAX-8_L3.0-W3.0-P0.65-LS4.9-BL-1~UMAX-8_ L3.0-W3.0-H1.1-LS4.9-P0.65~X9VW
LED-SEG-TH_SLR0394DRC5BD~LED-SEG-TH_ 12P-L39.9-W14.0-H7.0-P2.54-S11.3~X9VW
SW-TH_SK-12D07VG6~3Pins SPDT switch SK-12D07 1P2T~X9VW x 2
R0603~R0603~X9VW x 24
CONN-SMD_4P-P1.00_ XY-SM04B-SRSS-TB~SM04B-SRSS-TB--3DModel-STEP-269445~X9VW
R0402~R0402_L1.0-W0.5-H0.4~X9VW x 8
BAT-TH_CR2032-BS-6-1~BAT-SMD_L28.5-W16.0-H5.5-LS31.3_ CR2032-BS-6-1~X9VW
LED1206-FD_BULE~LED1206-FD_BULE~X9VW
LED1206-FD~LED1206-FD~X9VW x 2
HDR-TH_7P-P2.54-V-M-3~HDR-TH_7P-P2.54-V-M-3~X9VW x 2
POGO-TH_2P-P2.50-YZ215215105P-02025-01~POGO-TH_ 2P-P2.50-YZ215215105P-02025-01~X9VW x 2
HDR-TH_6P-P2.54-V-M-R2-C3-S2.54-1~HDR2.54-M-LI-2x3P~X9VW
SOT-23-3_L2.9-W1.3-P1.90-LS2.4-BR~SOT-23-3P_ L2.9-W1.3-H1.0-LS2.4-P0.95~X9VW x 4
BUZ-SMD_4P-L8.5-W8.5-P8.50-BR~BUZ-SMD_4P-L8.5-W8.5-H3.0~X9VW
VQFN-32_L5.0-W5.0-P0.50-TL-EP~VQFN-32_L5.0-W5.0-H1.0-P0.50~X9VW
C0603~C0603_L1.6-W0.8-H0.8~X9VW
SOD-523_L1.2-W0.8-LS1.6-RD~SOD-523_L1.2-W0.8-H0.7-LS1.6~X9VW
SOT-23-3_L3.0-W1.7-P0.95-LS2.9-BR~SOT-23-3L_ L2.9-W1.6-H1.1-LS2.8-P0.95~X9VW

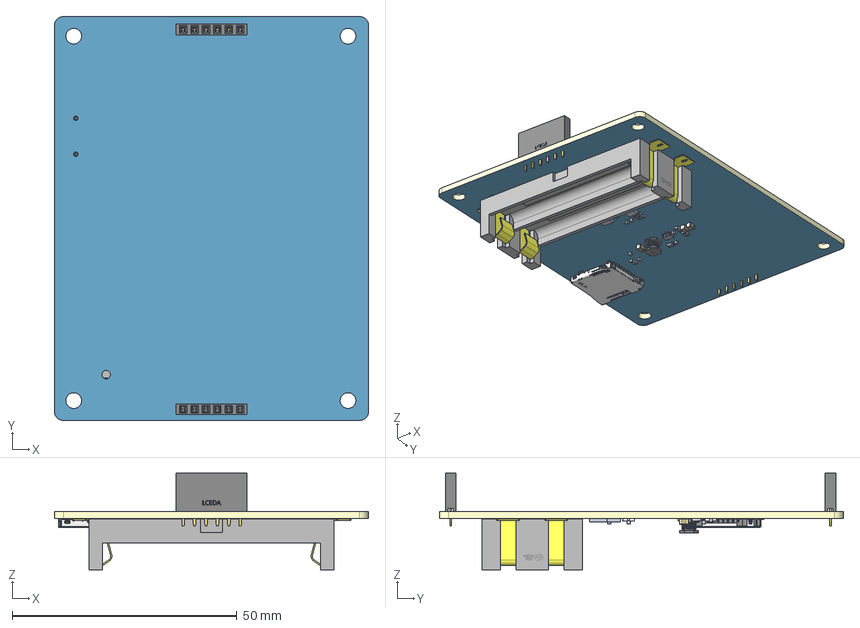
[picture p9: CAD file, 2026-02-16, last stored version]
boards/Megalops Power Board/3D_Powerboard PCB_2026-02-16.step
70.0 x 90.0 x 21.5 mm
Board~xcR4
TopCopper~xcR4
BottomCopper~xcR4
TopFpcStiffener~xcR4
BottomFpcStiffener~xcR4
C8~C0603~C0603_L1.6-W0.8-H0.8~xcR4 x 5
R10~R0805~R0805_L2.0-W1.3-H0.6~xcR4 x 2
HDR-TH_6P-P2.54-V-F~HDR-TH_6P-P2.54-V-F~xcR4 x 2
C0805~C0805_L2.0-W1.3-H1.3~xcR4 x 3
TSOT-23-6_L2.9-W1.6-P0.95-LS2.6-BL~TSOT-23-6_ L2.9-W1.6-P0.95-LS2.6-BL~xcR4
R0603~R0603~xcR4 x 6
BAT-SMD_BH-AAA-B5AA001~BAT-SMD_BH-AAA-B5AA001~xcR4
SOT-23-8_L3.0-W1.7-P0.65-LS2.8-BR~SOT-23-8_ L2.9-W1.6-H1.5-LS2.8-P0.65~xcR4
RES-SMD_L6.4-W3.2-R2512~RES-SMD_L6.4-W3.2-R2512~xcR4
IND-SMD_L4.5-W4.0~IND-SMD_L4.5-W4.0-H3.2~xcR4
TF-SMD_TF-015~TF-SMD_L14.8-W14.5-H1.9-P1.1~xcR4

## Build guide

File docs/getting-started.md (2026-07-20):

# 🦀 Getting Started with uFerris

## 📦 Platform Components

The uFerris platform consists of three components:

- **Megalops Baseboard** — The main uFerris board.
- **Megalops Power Extension Board** *(optional)* — Powerboard for the baseboard.
- **Seeed Studio XIAO Module** — Controller board for the uFerris baseboard.

To get started with uFerris you would need at minimum the baseboard and a XIAO board of your choice. For the purposes of this guide, the XIAO ESP32-C3 will be used.

## 🔍 Board Overview

### Megalops Baseboard

<p align="center">
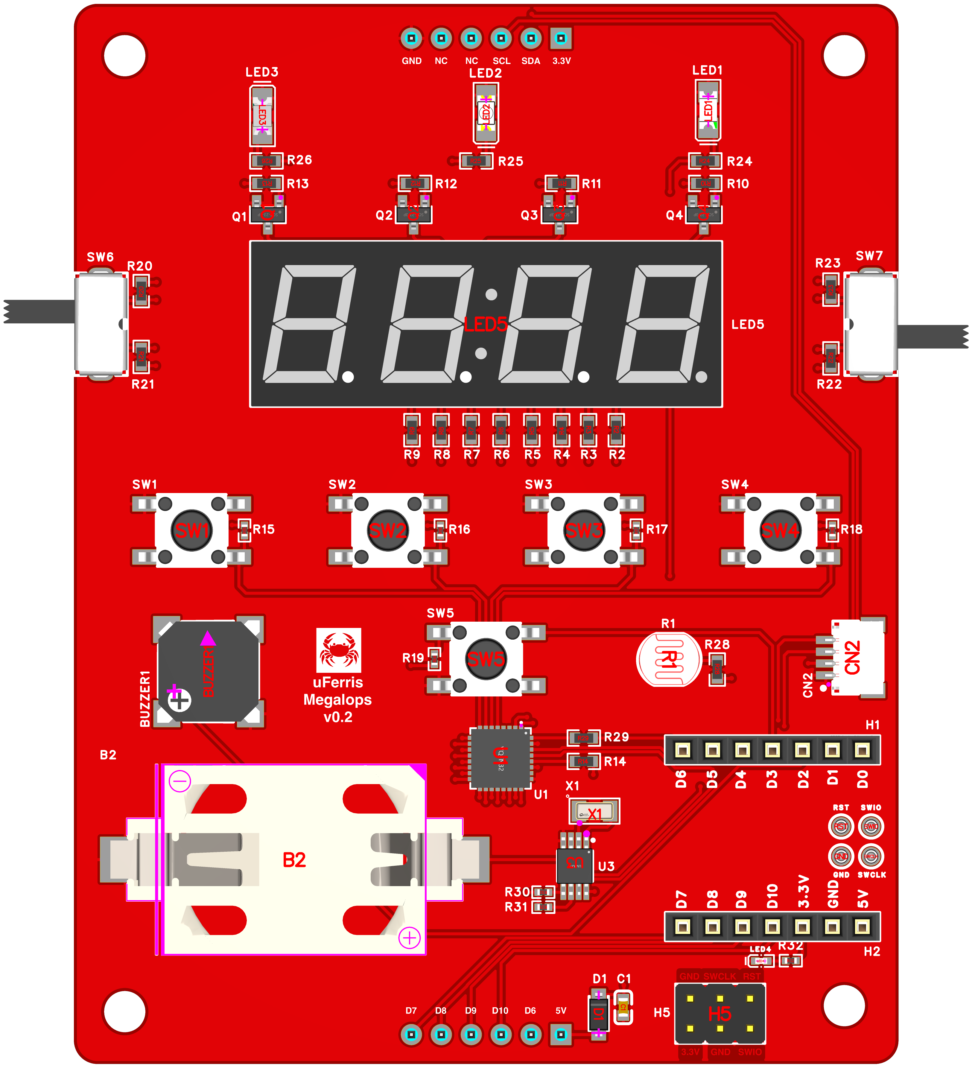
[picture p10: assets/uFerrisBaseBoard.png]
uFerris Baseboard
  
</p>

The Megalops baseboard is designed around the Seeed Studio XIAO platform. It supports multiple XIAO controllers, letting you swap MCUs while keeping the same board and peripherals. The board enables you to exercise every standard peripheral: GPIO, timers/counters, ADC, PWM, UART, and I²C.

Key components on the baseboard:

- 3 LEDs (1 direct GPIO, 2 via I/O expander)
- Buzzer (direct GPIO/PWM)
- 5 push buttons (1 direct GPIO, 4 via I/O expander)
- 2 toggle switches (via I/O expander)
- Light sensor (analog, direct GPIO)
- 4-digit 7-segment display (via I/O expander)
- TCA6424A I/O expander (I2C)

#### 🔋 Board Power

The uFerris is powered and controlled by the XIAO module. The XIAO module, in turn, can receive power from three different sources:

1. Via the USB-C connection on the XIAO.
2. Via the powerboard 2xAAA batteries.
3. Via the SWD debug connection.

> 📝 **NOTE:** The uFerris can still be powered by the USB-C connection while the powerboard is attached. However, flashing and serial communication might fail if the batteries are inserted.

### Megalops Power Extension Board (Optional)

<p align="center">
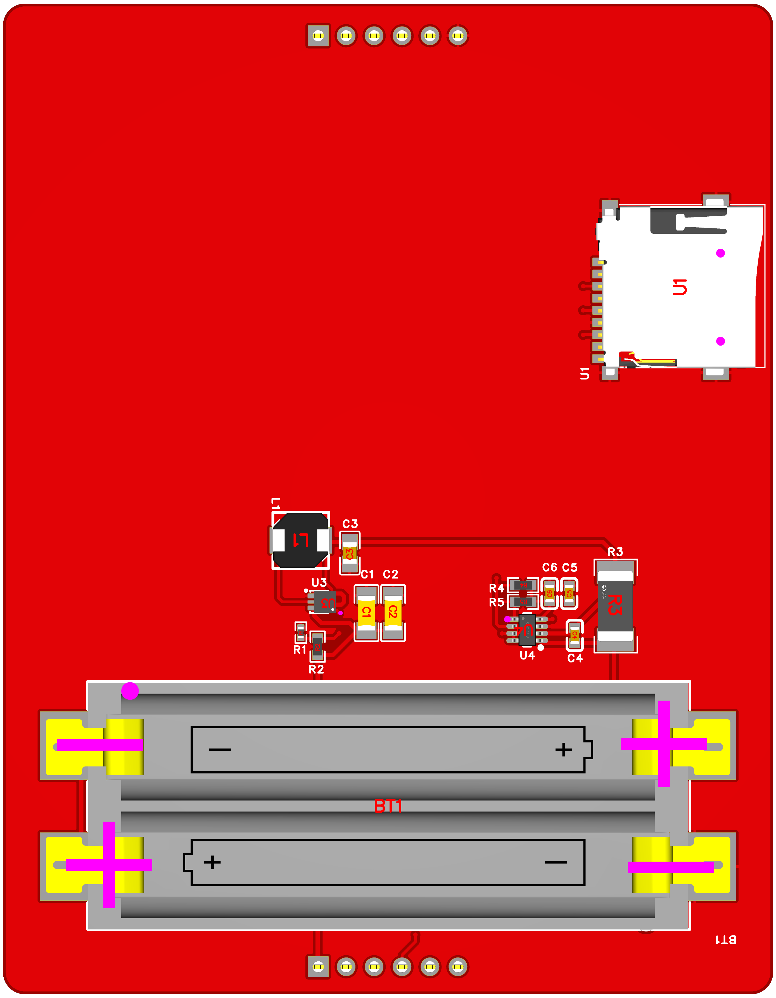
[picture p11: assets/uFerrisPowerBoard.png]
uFerris Powerboard
  
</p>

The power extension board is an optional add-on that enables standalone operation (Ex. running a program to collect data without a power cable).

Key components on the power board:

- 2×AAA battery holder.
- Current measurement circuit for power profiling.
- SD card slot for data logging (SPI).

## 🔧 Mounting Instructions

### XIAO Module Mounting
The XIAO module is mounted on the baseboard XIAO header. The figure below shows the mounting orientation for the XIAO module. Note how the USB connector of the module needs to always face outward.

<p align="center">
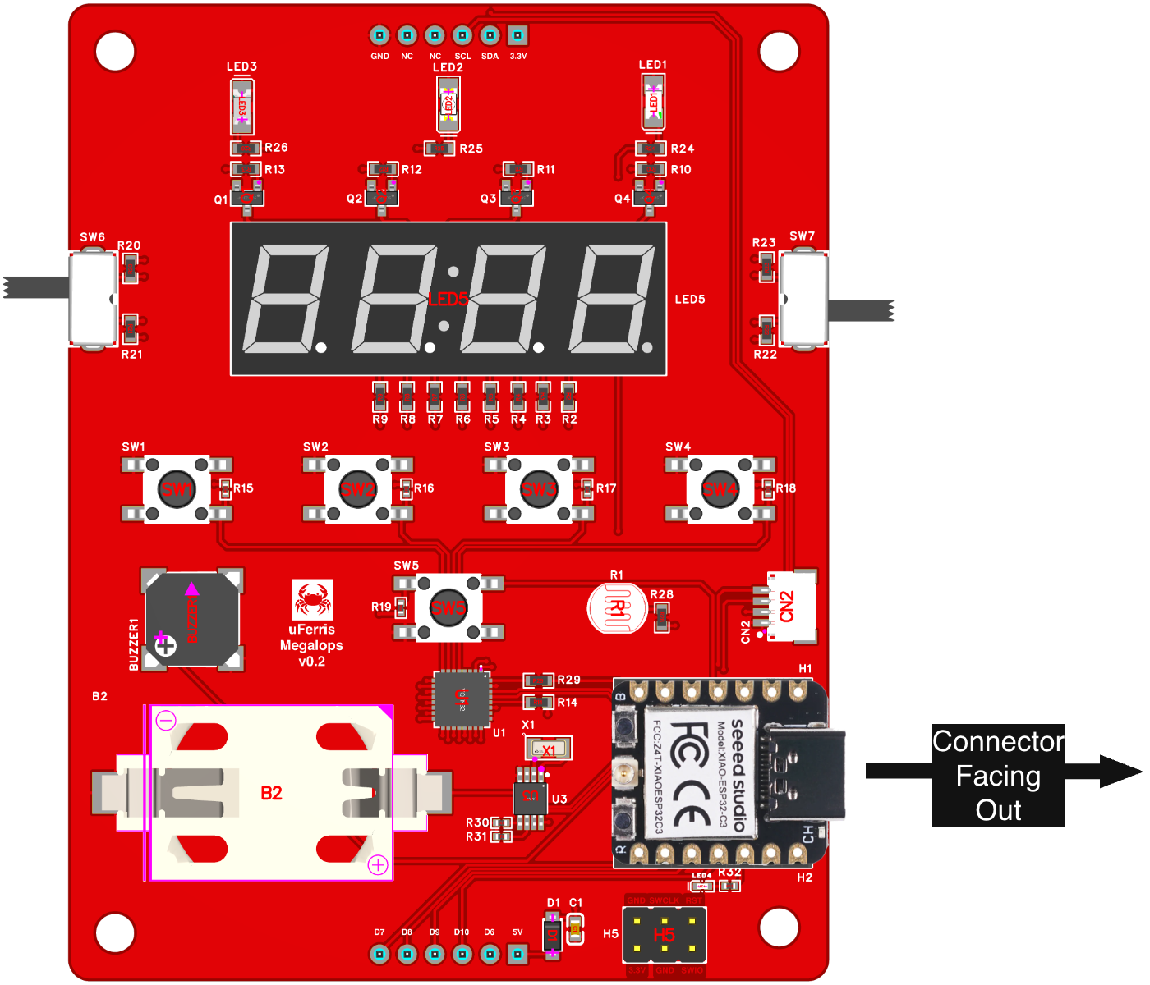
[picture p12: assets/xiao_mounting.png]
XIAO Mounting Orientation
  
</p>

### Power Extension Board Mounting
To mount the powerboard, align both top and bottom headers of the baseboard and the power extension board, then press down until the baseboard is firmly seated. The XIAO header on the baseboard and the battery holder on the powerboard should face **downward** as shown in the figure below.

More recent editions of the boards also have mounting markers as shown in the figure below. These markers indicated the mounting direction and need to align with each other.

> ⚠️ **WARNING:** Incorrect orientation of the power extension board will damage the baseboard and/or the XIAO. Always verify the orientation before powering the board.

<p align="center">
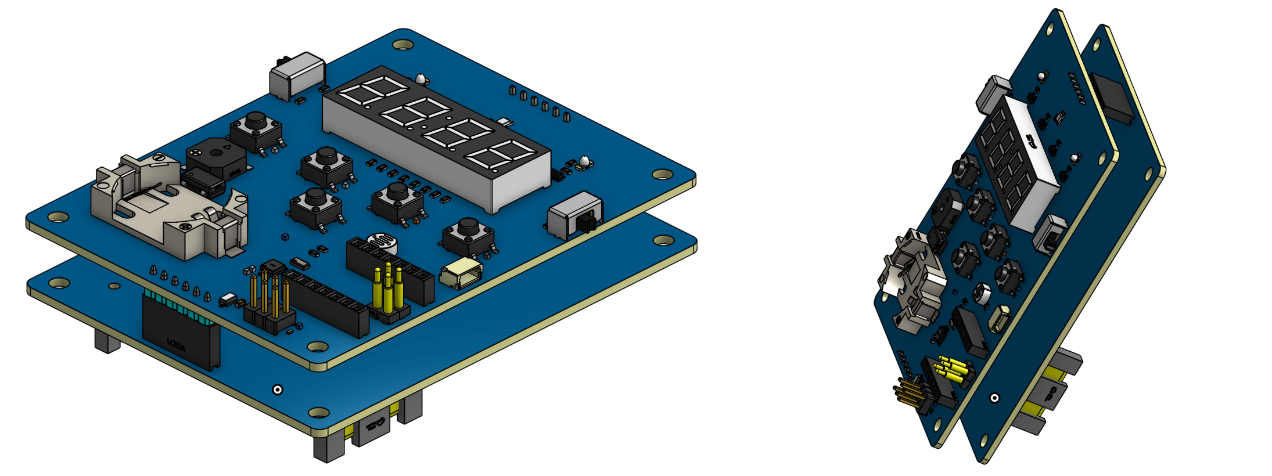
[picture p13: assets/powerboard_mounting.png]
Power Board Mounting
  
</p>

<p align="center">
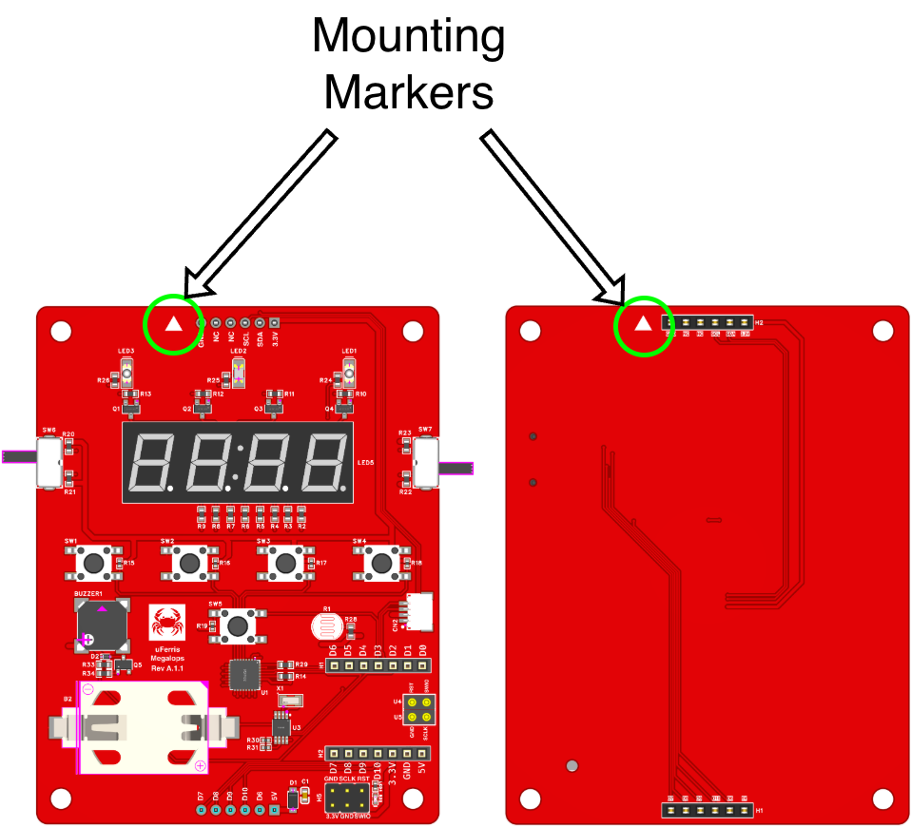
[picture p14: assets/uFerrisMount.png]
Board Mounting
  
</p>

## 📌 Baseboard Pinout Reference
Each component on the board has a unique reference ID and is wired either to the XIAO module or the I/O expander. The figure below labels the reference IDs for the different baseboard components. Additionally, the table below shows wiring mapping of the components to either of the device pins. 

> 📝 **NOTE:** The RTC, I/O Expander, and QWIIC connector are all wired to the SDA/SCL lines since they are I2C operated.

<p align="center">
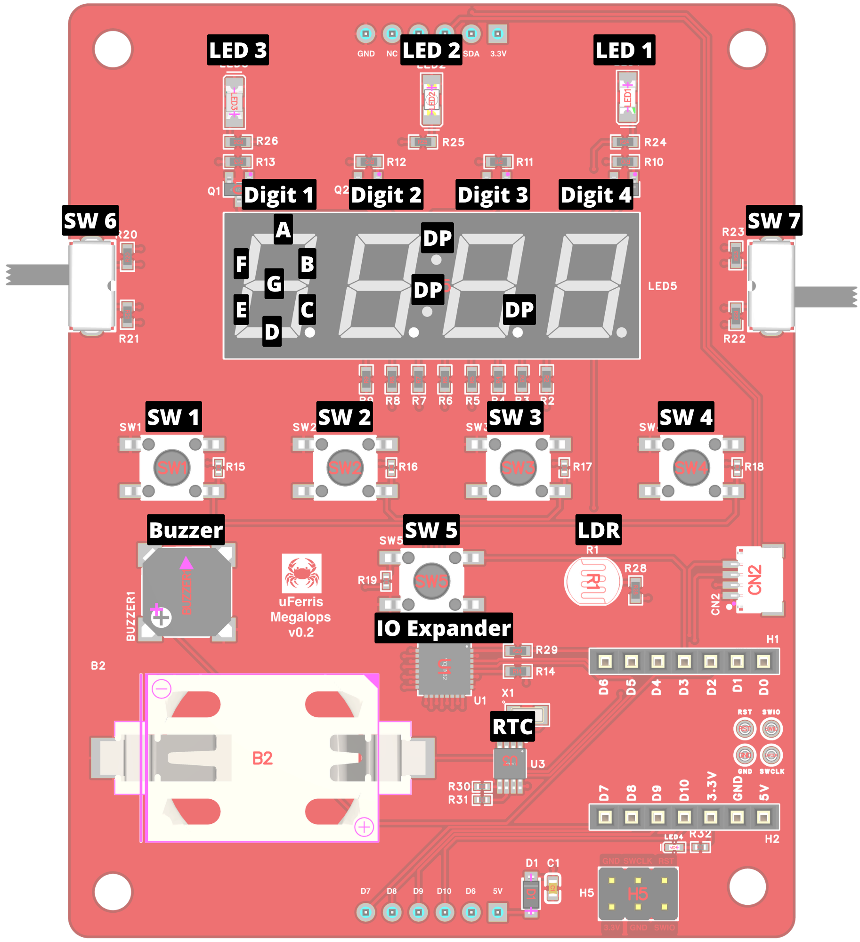
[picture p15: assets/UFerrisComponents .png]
uFerris Board
  
</p>

The table below provides a comprehensive mapping of the various components and their connections to the Xiao, I/O Expander, Bottom Header (H3), Top Header (H4), and ESP32-C3 pins. 

> **NOTE:** For up to data mappings for other XIAO devices, refer to the [uferris-hw repo](https://github.com/uFerris-rs/uferris-hw/tree/main/docs).

| Component Label | Component Connection | Xiao Pin  | I/O Expander Pin | Bottom Header Pin | Top Header Pin | Direction | ESP32-C3 Pin |
|:---|:---|:---|:---|:---|:---|:---|:---|
| Alarm | LED 1 | D1/A1  | - | - | - | Output | GPIO3 |
| LED | LED 2 | - | P14 | - | - | Output | - | 
| PM | LED 3 | - | P15 | - | - | Output | - | 
| - | Buzzer | D2/A2  | - | - | - | Output | GPIO4 | 
| Hour | SW1 | - | P07 | - | - | Input | - |
| Minute | SW2 | - | P06 | - | - | Input | - | 
| Time | SW3 | - | P05 | - | - | Input | - |
| Alarm | SW4 | - | P04 | - | - | Input | - | 
| Snooze | SW5 | D3 | - | - | - | Input | GPIO5 | 
| 12 | SW6 Pos 1 | - | P16 | - | - | Input | - | 
| 24 | SW6 Pos 2 | - | P17 | - | - | Input | - | 
| On | SW7 Pos 1 | - | P00 | - | - | Input | - | 
| Off | SW7 Pos 2 | - | P01 | - | - | Input | - | 
| - | SDA | D4 | - | - | P2 | Comms | GPIO6 | 
| - | SCL | D5 | - | - | P3 | Comms | GPIO7 | 
| - | LDR | D0/A0  | - | - | - | Analog | GPIO2 | 
| - | Digit 1 | - | P10 | - | - | Output | - | 
| - | Digit 2 | - | P11 | - | - | Output | - | 
| - | Digit 3 | - | P12 | - | - | Output | - | 
| - | Digit 4 | - | P13 | - | - | Output | - | 
| - | Seg A | - | P20 | - | - | Output | - | 
| - | Seg B | - | P21 | - | - | Output | - | 
| - | Seg C | - | P22 | - | - | Output | - | 
| - | Seg D | - | P23 | - | - | Output | - | 
| - | Seg E | - | P24 | - | - | Output | - | 
| - | Seg F | - | P25 | - | - | Output | - | 
| - | Seg G | - | P27 | - | - | Output | - | 
| - | DP | - | P26 | - | - | Output | - | 
| - | XiaoTx | D6 | nINT | P2 | - | - | GPIO21 | 
| - | XiaoMosi | D10 | - | P3 | - | - | GPIO10 | 
| - | XiaoMiso | D9 | - | P4 | - | - | GPIO9 | 
| - | XiaoScl | D8 | - | P5 | - | - | GPIO8 | 
| - | XiaoRx | D7 | - | P6 | - | - | GPIO20 | 

## 🛠️ Toolchain Setup

1. **Install Rust**

```bash
curl --proto '=https' --tlsv1.2 -sSf https://sh.rustup.rs | sh
```

2. **Add the RISC-V Target** (for ESP32-C3)

```bash
rustup target add riscv32imc-unknown-none-elf
```

> 📝 **NOTE:** The target refers to the architecture being targeted by the cross-compiler for the device you want to generate code for. Each XIAO device would probably have a different one.

3. **Install espflash**

```bash
cargo install espflash --locked
```

4. **Install esp-generate**

```bash
cargo install esp-generate --locked
```

## 🚀 Your First Project

1. **Generate a New Project**

```bash
esp-generate --chip esp32c3 -o unstable-hal -o vscode -o esp-backtrace -o log --headless blinky
cd blinky
```

> 📝 **NOTE:** While Espressif offers `esp-generate` to generate projects, this step might be different for non-ESP XIAO devices.

2. **Write the Blink Code**

Replace the contents of `src/main.rs` with:

```rust
#![no_std]
#![no_main]

use esp_backtrace as _;
use esp_hal::delay::Delay;
use esp_hal::gpio::{Level, Output, OutputConfig};
use log::info;

esp_bootloader_esp_idf::esp_app_desc!();

#[esp_hal::main]
fn main() -> ! {
    let config = esp_hal::Config::default();
    let peripherals = esp_hal::init(config);

    let mut led = Output::new(peripherals.GPIO3, Level::Low, OutputConfig::default());
    let delay = Delay::new();

    info!("Blinking LED 1!");

    loop {
        led.toggle();
        delay.delay_millis(500);
    }
}
```

3. **Connect and Flash**

Connect the XIAO to your laptop via USB-C, then build and flash:

```bash
cargo run --release
```

You should see LED 1 on the uFerris board blinking. 🎉

## 📚 Running the BSP Demo

The uFerris BSP provides a hardware-agnostic API that works across all supported XIAO controllers.

**BSP Repository:** [https://github.com/uFerris-rs/uferris-bsp](https://github.com/uFerris-rs/uferris-bsp)

1. **Clone the BSP Repository**

```bash
git clone https://github.com/uFerris-rs/uferris-bsp.git
cd uferris-bsp
```

2. **Run an Example**

```bash
cd examples/xiao-esp32c3
cargo run --bin blinky
```

> ❗️ **IMPORTANT:** The BSP uses Cargo feature flags to select your XIAO controller and optional extensions. It assumes the power board extension board is attached and enables the `power-board` feature flag. As such, if the powerboard is not attached, the run might fail. As such, in your project's `Cargo.toml`, enable or disable the features to match your setup. For the latest feature list, always refer to the [uferris-bsp crate documentation](https://crates.io/crates/uferris-bsp). 

## 🔗 Useful Links

- **uFerris BSP:** [https://github.com/uFerris-rs/uferris-bsp](https://github.com/uFerris-rs/uferris-bsp)
- **uFerris Hardware:** [https://github.com/uFerris-rs/uferris-hw](https://github.com/uFerris-rs/uferris-hw)
- **ESP Rust Documentation:** [https://docs.espressif.com/projects/rust/](https://docs.espressif.com/projects/rust/)
- **Simplified Embedded Rust (Book):** [https://www.theembeddedrustacean.com/](https://www.theembeddedrustacean.com/)

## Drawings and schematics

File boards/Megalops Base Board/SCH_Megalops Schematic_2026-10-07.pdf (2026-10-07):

I/O Expander | Telemetry Headers | Seven Segment LED

# Slide Switches

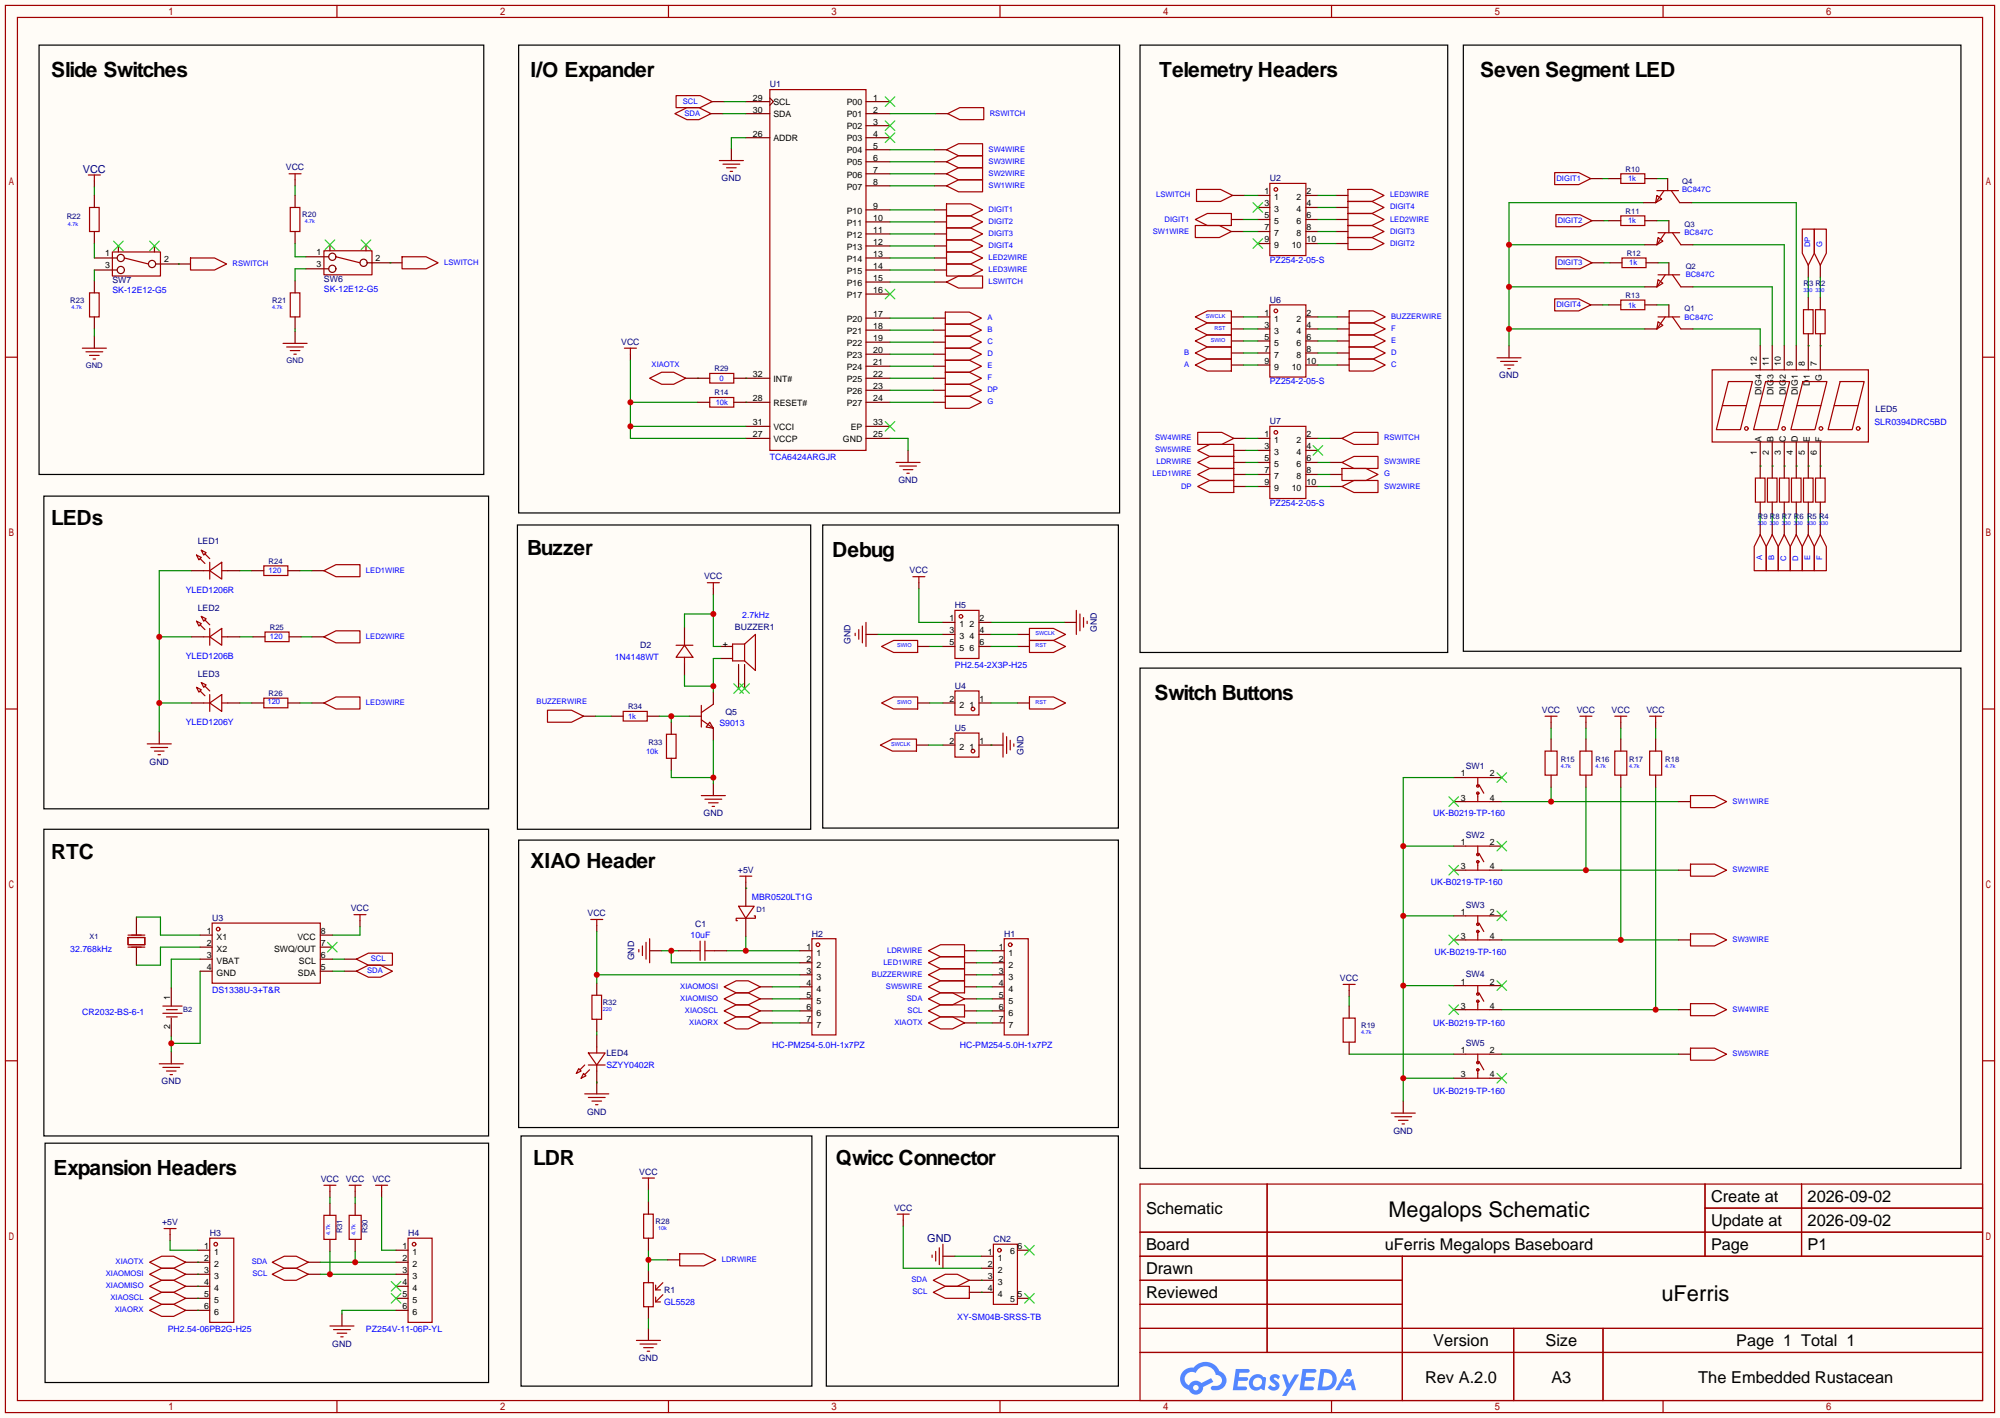
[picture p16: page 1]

Schematic | Megalops Schematic | Create at | 2026-09-02

Update at | 2026-09-02

Board | uFerris Megalops Baseboard | Page | P1
Drawn | | uFerris
Reviewed

Version | Size | Page 1 Total 1
Rev A.2.0 | A3 | The Embedded Rustacean

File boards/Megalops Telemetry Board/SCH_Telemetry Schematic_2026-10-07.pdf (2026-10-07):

# Signal Multiplexers

# Telemetry Headers

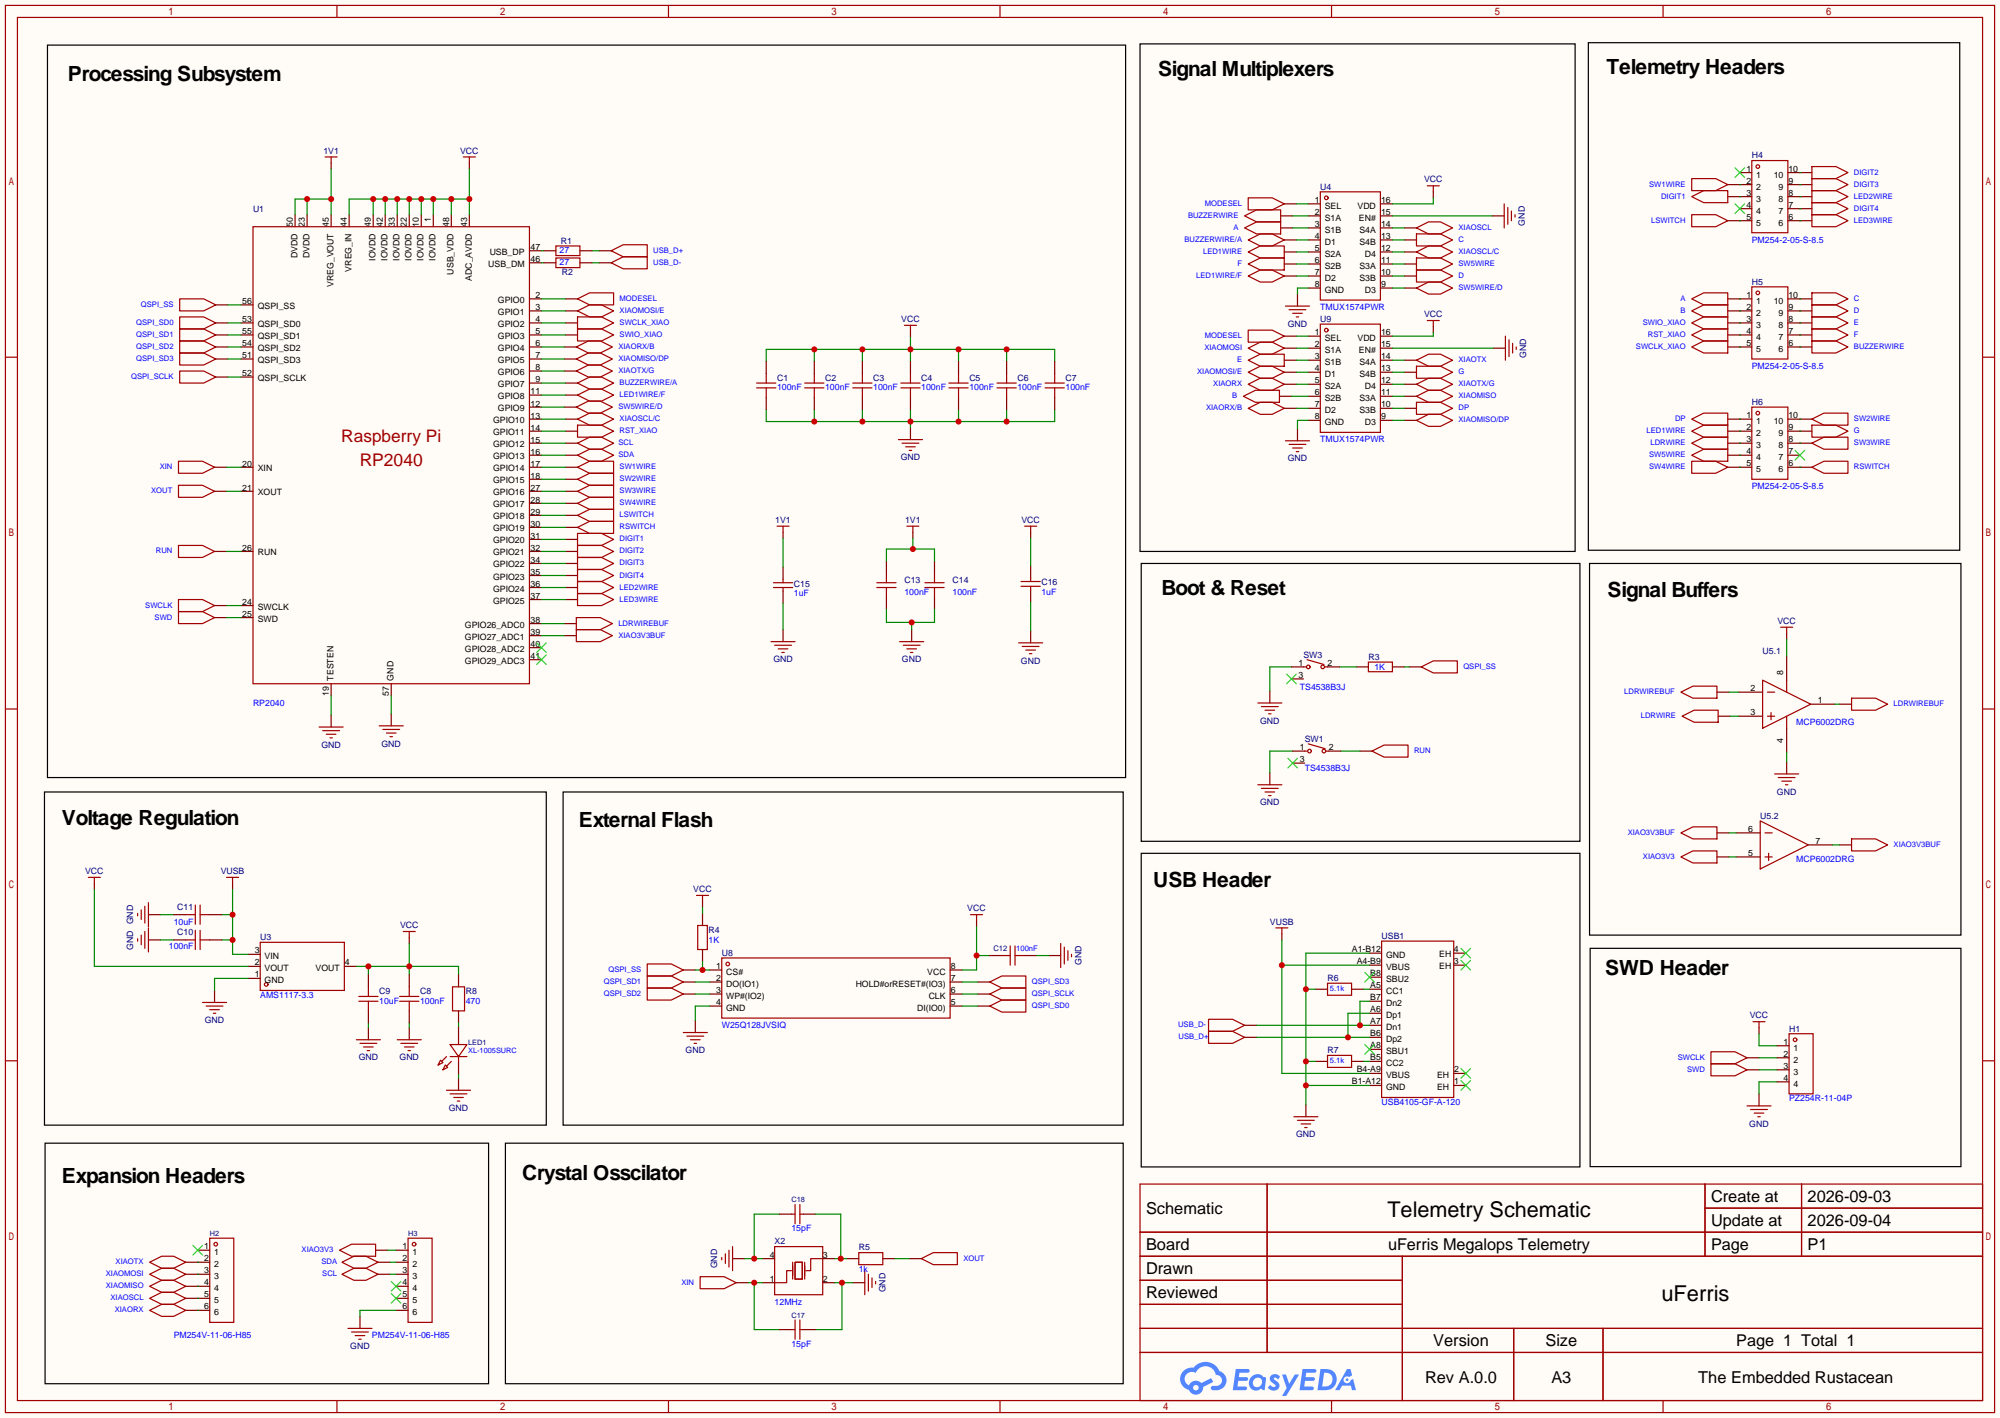
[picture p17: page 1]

Schematic | Telemetry Schematic | Create at | 2026-09-03

Update at | 2026-09-04

Board | uFerris Megalops Telemetry | Page | P1
Drawn | | uFerris
Reviewed

Version | Size | Page 1 Total 1
Rev A.0.0 | A3 | The Embedded Rustacean

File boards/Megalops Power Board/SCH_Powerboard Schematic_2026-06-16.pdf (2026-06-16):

5V Voltage Regulation | Current Sensing

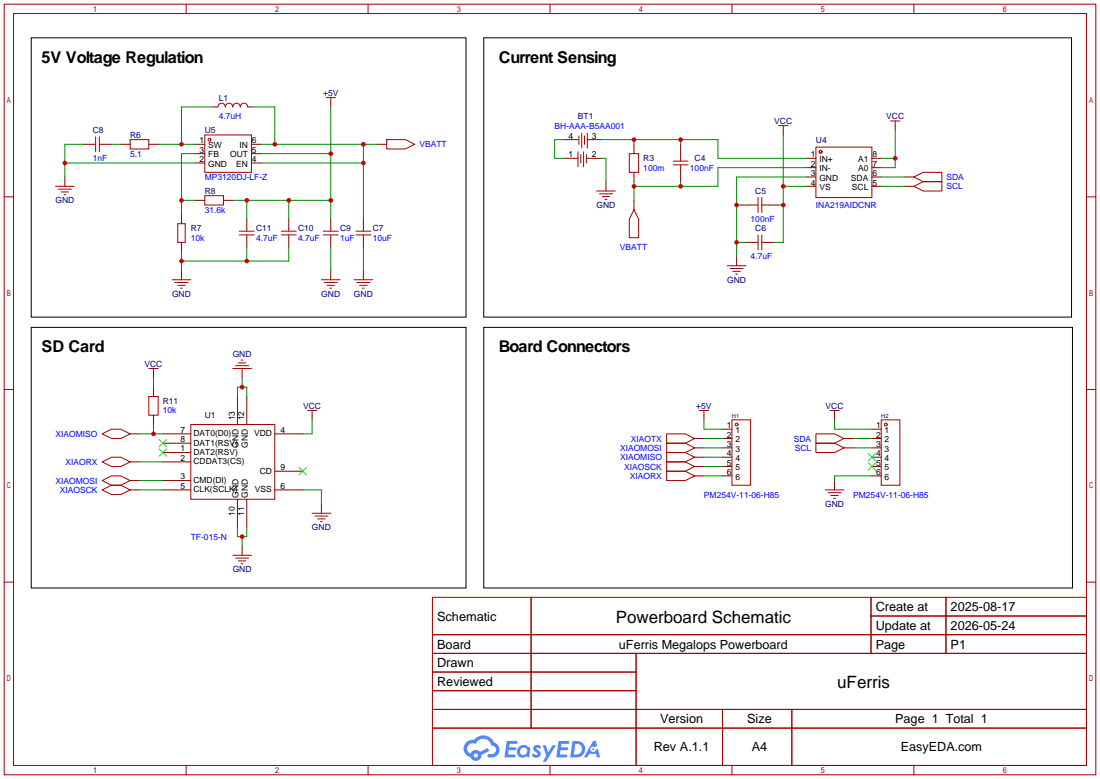
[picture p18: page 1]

GND 12 GND 11 GND 10 GND 13
VDD 4

Schematic | Powerboard Schematic | Create at | 2025-08-17

Update at | 2026-05-24

Board | uFerris Megalops Powerboard | Page | P1
Drawn | | uFerris
Reviewed

Version | Size | Page 1 Total 1
Rev A.1.1 | A4 | EasyEDA.com

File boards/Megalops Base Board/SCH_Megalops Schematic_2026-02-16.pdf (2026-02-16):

I/O Expander | Seven Segment LED

# Slide Switches

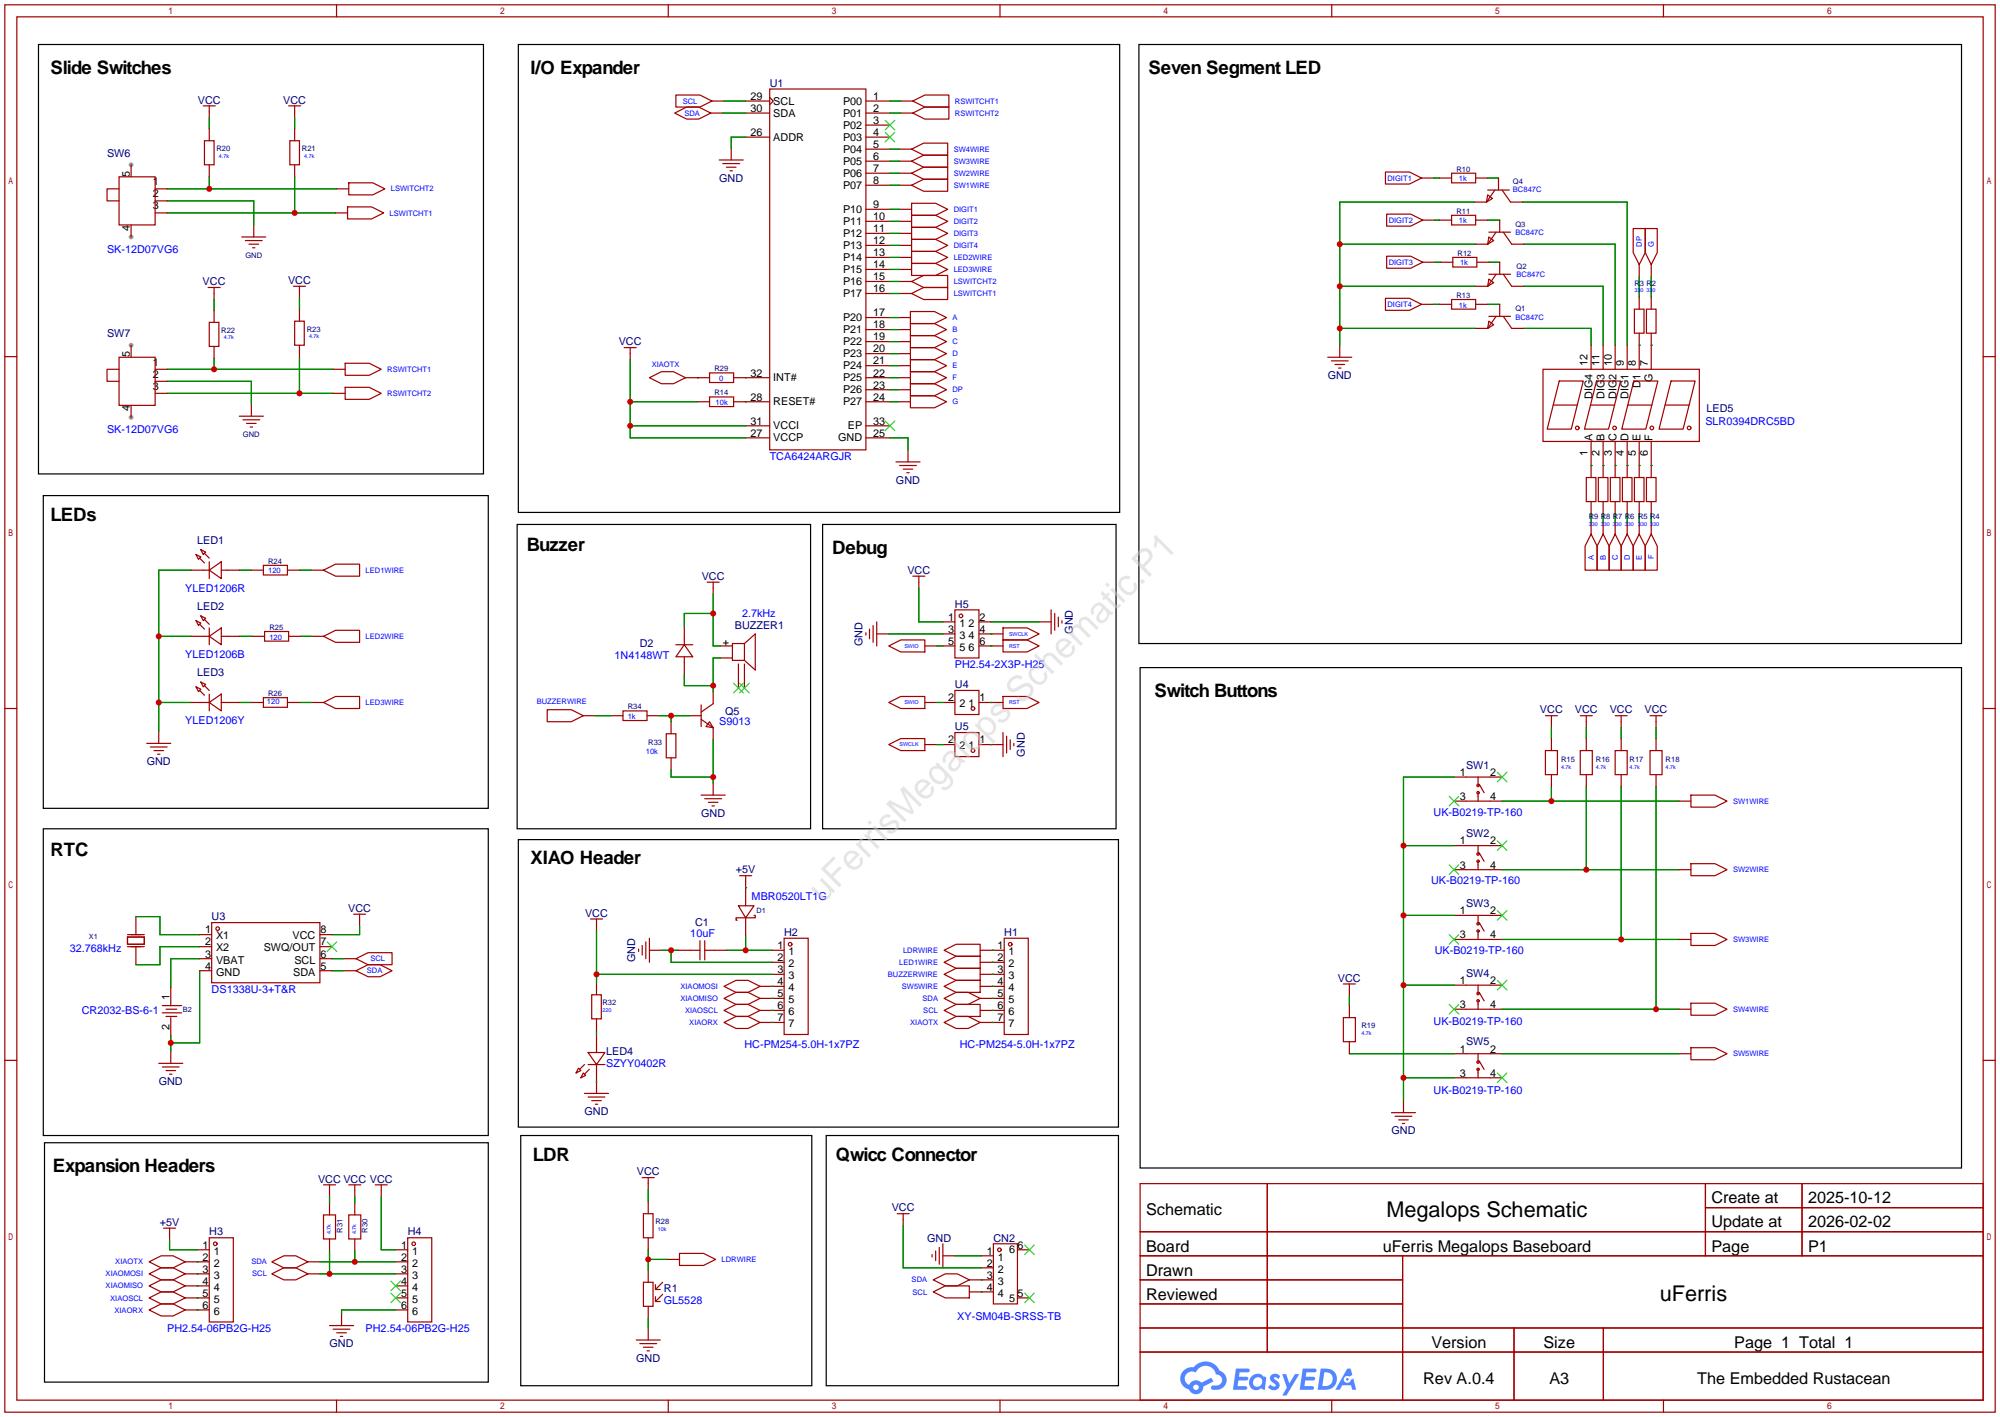
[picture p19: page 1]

VCC VCC

Schematic | Megalops Schematic | Create at | 2025-10-12

Update at | 2026-02-02

Board | uFerris Megalops Baseboard | Page | P1
Drawn | | uFerris
Reviewed

Version | Size | Page 1 Total 1
Rev A.0.4 | A3 | The Embedded Rustacean

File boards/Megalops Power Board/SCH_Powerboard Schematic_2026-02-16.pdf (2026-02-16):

5V Voltage Regulation | Current Sensing

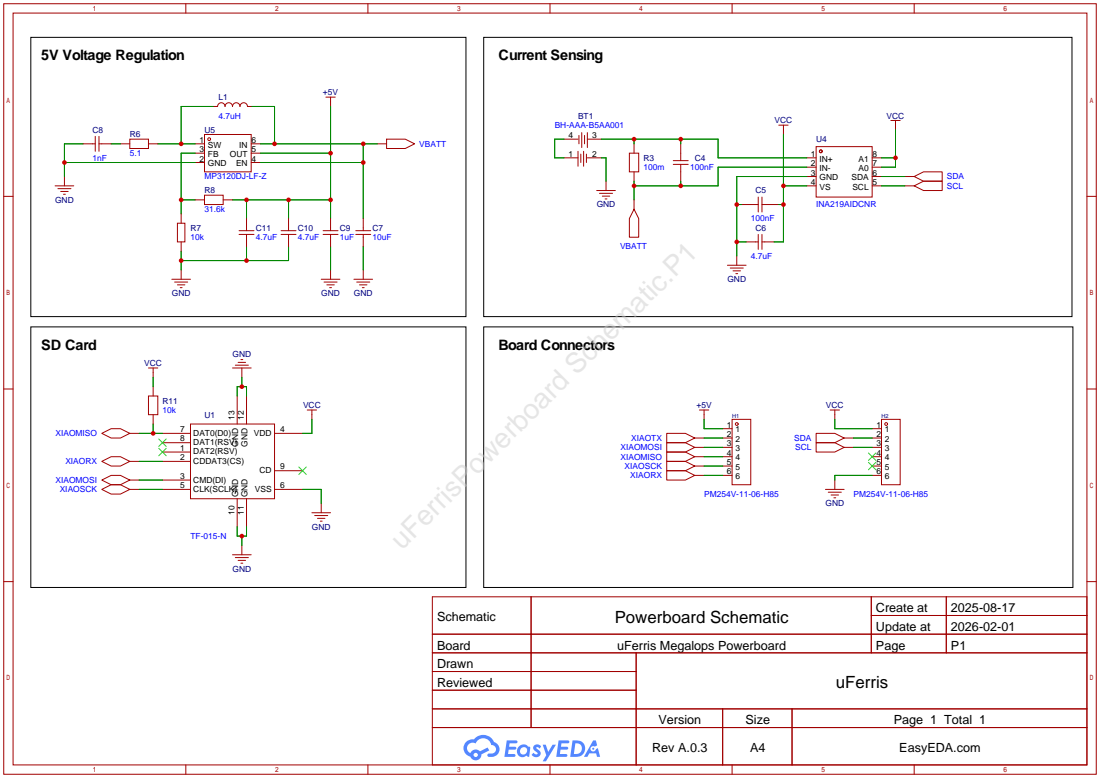
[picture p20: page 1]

GND 12 GND 11 GND 10 GND 13
VDD 4

Schematic | Powerboard Schematic | Create at | 2025-08-17

Update at | 2026-02-01

Board | uFerris Megalops Powerboard | Page | P1
Drawn | | uFerris
Reviewed

Version | Size | Page 1 Total 1
Rev A.0.3 | A4 | EasyEDA.com

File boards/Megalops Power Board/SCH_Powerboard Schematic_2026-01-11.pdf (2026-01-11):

5V Voltage Regulation | Current Sensing

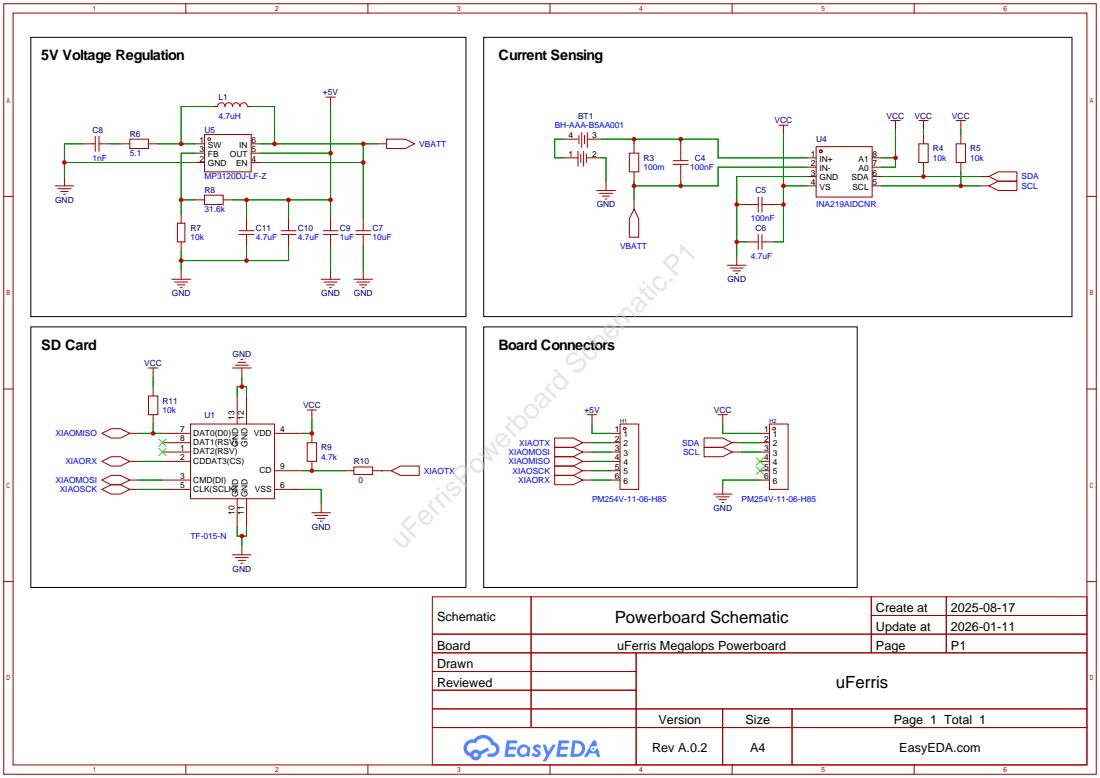
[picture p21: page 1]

GND 12 GND 11 GND 10 GND 13
VDD 4

Schematic | Powerboard Schematic | Create at | 2025-08-17

Update at | 2026-01-11

Board | uFerris Megalops Powerboard | Page | P1
Drawn | | uFerris
Reviewed

Version | Size | Page 1 Total 1
Rev A.0.2 | A4 | EasyEDA.com

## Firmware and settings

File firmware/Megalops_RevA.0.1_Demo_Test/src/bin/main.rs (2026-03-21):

#![no_std]
#![no_main]

use bitmask_enum::bitmask;
use core::cell::RefCell;
use embassy_executor::Spawner;
use embassy_sync::blocking_mutex::raw::CriticalSectionRawMutex;
use embassy_sync::blocking_mutex::Mutex;
use embassy_time::{Duration, Timer};
use esp_backtrace as _;
use esp_hal::analog::adc::{Adc, AdcConfig, Attenuation};
use esp_hal::clock::CpuClock;
use esp_hal::gpio::{Input, InputConfig, Level, Output, OutputConfig, Pull};
use esp_hal::i2c::master::{Config as I2cConfig, I2c};
use esp_hal::ledc::{
    channel, channel::ChannelIFace, timer, timer::Timer as LedcTimer, timer::TimerIFace,
    LSGlobalClkSource, Ledc, LowSpeed,
};
use esp_hal::time::Rate;
use esp_hal::timer::systimer::SystemTimer;
use esp_hal::Blocking;
use esp_println::println;
extern crate alloc;

esp_bootloader_esp_idf::esp_app_desc!();

// TCA6424 Commands
const TCA6424_ADDR: u8 = 0x22; // I2C address of the TCA6424
const IN_PORT0: u8 = 0x80; // Input Port 0 Register
const IN_PORT1: u8 = 0x81; // Input Port 1 Register
const IN_PORT2: u8 = 0x82; // Input Port 2 Register
const OUT_PORT0: u8 = 0x84; // Output Port 0 Register
const OUT_PORT1: u8 = 0x85; // Output Port 1 Register
const OUT_PORT2: u8 = 0x86; // Output Port 2 Register
const POL_INV_PORT0: u8 = 0x88; // Polarity Inversion Port 0 Register
const POL_INV_PORT1: u8 = 0x89; // Polarity Inversion Port 1 Register
const POL_INV_PORT2: u8 = 0x8A; // Polarity Inversion Port 2 Register
const CONFIG_PORT0: u8 = 0x8C; // Configuration Port 0 Register
const CONFIG_PORT1: u8 = 0x8D; // Configuration Port 1 Register
const CONFIG_PORT2: u8 = 0x8E; // Configuration Port 2 Register

const RTC_ADDR: u8 = 0x68;

#[bitmask(u8)]
pub enum IoExpPort0 {
    Sw7Pos1, // Port 0 Pin 0
    Sw7Pos2, // Port 0 Pin 1
    P02,     // Port 0 Pin 2 (Unused)
    Sw4,     // Port 0 Pin 3
    Sw3,     // Port 0 Pin 4
    Sw2,     // Port 0 Pin 5
    Sw1,     // Port 0 Pin 6
    SegG,    // Port 0 Pin 7
}

#[bitmask(u8)]
pub enum IoExpPort1 {
    Dp,   // Port 1 Pin 0
    SegA, // Port 1 Pin 1
    SegB, // Port 1 Pin 2
    SegC, // Port 1 Pin 3
    SegD, // Port 1 Pin 4
    SegE, // Port 1 Pin 5
    SegF, // Port 1 Pin 6
    P17,  // Port 1 Pin 7 (Unused)
}

#[bitmask(u8)]
pub enum IoExpPort2 {
    Digit4,  // Port 2 Pin 0
    Digit3,  // Port 2 Pin 1
    Digit2,  // Port 2 Pin 2
    Digit1,  // Port 2 Pin 3
    Led3,    // Port 2 Pin 4
    Led2,    // Port 2 Pin 5
    Sw6Pos1, // Port 2 Pin 6
    Sw6Pos2, // Port 2 Pin 7
}

// Direction Configuration for TCA6424
// Port 0: All outputs except for SW7 and SW4
// Port 1: All outputs except for DP, SegA, SegB, SegC
// Port 2: All outputs except for Digit4, Digit3, Digit2, Digit
const PORT0_DIR: u8 = 0x7F;
const PORT1_DIR: u8 = 0x00;
const PORT2_DIR: u8 = 0xC0;

// Mutex to Share same I2C singleton across threads
static SHARED_I2C: Mutex<CriticalSectionRawMutex, RefCell<Option<I2c<'static, Blocking>>>> =
    Mutex::new(RefCell::new(None));

// Function to convert to BCD from decimal (for RTC)
fn to_bcd(val: u8) -> u8 {
    ((val / 10) << 4) | (val % 10)
}

// Function to convert from BCD
fn from_bcd(val: u8) -> u8 {
    10 * (val >> 4) + (val & 0x0F)
}

// Function to set RTC device parameters
fn set_rtc(
    i2c: &mut I2c<'static, Blocking>,
    year: u16,
    month: u8,
    day: u8,
    hour: u8,
    min: u8,
    sec: u8,
) {
    let year_u8 = (year - 2000) as u8;
    let sec_bcd = to_bcd(sec);
    let min_bcd = to_bcd(min);
    let hour_bcd = to_bcd(hour);
    let day_bcd = to_bcd(day);
    let weekday_bcd = to_bcd(5);
    let month_bcd = to_bcd(month);
    let year_bcd = to_bcd(year_u8);
    i2c.write(
        RTC_ADDR,
        &[
            0x00,
            sec_bcd,
            min_bcd,
            hour_bcd,
            weekday_bcd,
            day_bcd,
            month_bcd,
            year_bcd,
        ],
    )
    .unwrap();
}

// Function to read RTC parameters
fn read_rtc(i2c: &mut I2c<Blocking>) -> (u16, u8, u8, u8, u8, u8) {
    let mut buf = [0u8; 7];
    i2c.write_read(RTC_ADDR, &[0x00], &mut buf).unwrap();
    let sec = from_bcd(buf[0] & 0x7F);
    let min = from_bcd(buf[1] & 0x7F);
    let hour = from_bcd(buf[2] & 0x3F);
    let day = from_bcd(buf[4] & 0x3F);
    let month = from_bcd(buf[5] & 0x1F);
    let year = from_bcd(buf[6]) as u16 + 2000;
    (year, month, day, hour, min, sec)
}

// Test Sequence:
// Spawn LED Task to Blink all LEDs
// Spawn Seven Segment Display Task to Cycle through all segments
// Spawn Buzzer Task to Buzz at 2 second intervals
// Read LDR (currently unavailable)
// Set RTC to some value (e.g., 2025-08-01 12:00:00)
// Wait 2 seconds (show message)
// Read RTC value and print it
// User Interaction Tests: Prompt user to press any button or slide switch
// On every user (button/switch) interaction, print the button pressed or switch toggled

#[esp_hal_embassy::main]
async fn main(spawner: Spawner) {
    let config = esp_hal::Config::default().with_cpu_clock(CpuClock::max());
    let peripherals = esp_hal::init(config);

    esp_alloc::heap_allocator!(size: 64 * 1024);

    let timer0 = SystemTimer::new(peripherals.SYSTIMER);
    esp_hal_embassy::init(timer0.alarm0);

    // XIAO GPIO Pin Configuration
    let led1 = Output::new(peripherals.GPIO3, Level::Low, OutputConfig::default());
    let sw5 = Input::new(
        peripherals.GPIO5,
        InputConfig::default().with_pull(Pull::Up),
    );

    // Master I2C Configuration
    // Bus Addresses:
    // RTC -> 0x68
    // I/O Expander -> 0x22
    // Pins:
    // SCL -> GPIO7 on XIAO
    // SDA -> GPIO6 on XIAO
    let mut i2c0 = I2c::new(
        peripherals.I2C0,
        I2cConfig::default().with_frequency(Rate::from_khz(100)),
    )
    .unwrap()
    .with_scl(peripherals.GPIO7)
    .with_sda(peripherals.GPIO6);

    // Configure I/O Expander pins before moving I2C to shared state
    // Write I/O Direction to TCA6424 Config Registers
    i2c0.write(
        TCA6424_ADDR,
        &[CONFIG_PORT0, PORT0_DIR, PORT1_DIR, PORT2_DIR],
    )
    .unwrap();
    

    // Move I2C to shared state to share among tasks
    SHARED_I2C.lock(|i2c| i2c.borrow_mut().replace(i2c0));

    // Configure Buzzer PWM
    // Buzzer connected to GPIO2 on XIAO
    // Create LEDC instance with low speed global clock
    let mut buzz = Ledc::new(peripherals.LEDC);
    buzz.set_global_slow_clock(LSGlobalClkSource::APBClk);

    // Configure LEDC timer
    let timer = buzz.timer::<LowSpeed>(timer::Number::Timer0);

    // Configure LEDC Channel Attaching Timer and Pin
    let buzz_channel = buzz.channel(channel::Number::Channel0, peripherals.GPIO2);

    // Spawn LED, Seven Seg, and Buzzer tasks
    spawner.spawn(led_task(led1)).unwrap();
    spawner.spawn(sseg_task()).unwrap();
    spawner.spawn(buzzer_task(buzz_channel, timer)).unwrap();

    // Read LDR (currently unavailable)
    println!("Reading LDR (currently unavailable)");

    // Set RTC to some value (e.g., 2025-08-01 12:00:00)
    SHARED_I2C.lock(|cell| {
        let mut i2c_ref = cell.borrow_mut();
        let i2c = i2c_ref.as_mut().unwrap();
        set_rtc(i2c, 2025, 8, 1, 12, 0, 0);
    });
    println!("RTC set to 2025-08-01 12:00:00");

    // Wait 2 seconds (show message)
    println!("Waiting 2 seconds...");
    Timer::after(Duration::from_secs(2)).await;

    // Read RTC value and print it
    SHARED_I2C.lock(|cell| {
        let mut i2c_ref = cell.borrow_mut();
        let i2c = i2c_ref.as_mut().unwrap();
        let (y, m, d, h, min, s) = read_rtc(i2c);
        println!(
            "RTC value: {:04}-{:02}-{:02} {:02}:{:02}:{:02}",
            y, m, d, h, min, s
        );
    });

    println!("To Test Buttons, Press Any Button or Slide a Switch");

    #[derive(PartialEq, Debug, Clone, Copy)]
    enum Swstate {
        Top,
        Bottom,
        Undefined,
    }

    let mut crswstate = Swstate::Undefined;
    let mut clswstate = Swstate::Undefined;
    let mut prswstate = Swstate::Undefined;
    let mut plswstate = Swstate::Undefined;
    let mut port0 = 0u8;
    let mut port2 = 0u8;

    SHARED_I2C.lock(|cell| {
        let mut i2c_ref = cell.borrow_mut();
        let i2c = i2c_ref.as_mut().unwrap();
        let mut rbuf = [0u8];
        i2c.write_read(TCA6424_ADDR, &[IN_PORT0], &mut rbuf)
            .unwrap();
        port0 = rbuf[0];
        i2c.write_read(TCA6424_ADDR, &[IN_PORT2], &mut rbuf)
            .unwrap();
        port2 = rbuf[0];
    });

    if port0 & IoExpPort0::Sw7Pos1.bits() != 0 {
        crswstate = Swstate::Top;
        prswstate = Swstate::Top;
    }
    if port0 & IoExpPort0::Sw7Pos2.bits() != 0 {
        crswstate = Swstate::Bottom;
        prswstate = Swstate::Bottom;
    }
    if port2 & IoExpPort2::Sw6Pos1.bits() != 0 {
        clswstate = Swstate::Bottom;
        plswstate = Swstate::Bottom;
    }
    if port2 & IoExpPort2::Sw6Pos2.bits() != 0 {
        clswstate = Swstate::Top;
        plswstate = Swstate::Top;
    }

    loop {
        let mut interaction_detected = false;

        SHARED_I2C.lock(|cell| {
            let mut i2c_ref = cell.borrow_mut();
            let i2c = i2c_ref.as_mut().unwrap();
            let mut rbuf = [0u8];
            i2c.write_read(TCA6424_ADDR, &[IN_PORT0], &mut rbuf)
                .unwrap();
            port0 = rbuf[0];
            i2c.write_read(TCA6424_ADDR, &[IN_PORT2], &mut rbuf)
                .unwrap();
            port2 = rbuf[0];
        });

        if port0 & IoExpPort0::Sw1.bits() == 0 {
            println!("SW1 pressed");
            interaction_detected = true;
        }
        if port0 & IoExpPort0::Sw2.bits() == 0 {
            println!("SW2 pressed");
            interaction_detected = true;
        }
        if port0 & IoExpPort0::Sw3.bits() == 0 {
            println!("SW3 pressed");
            interaction_detected = true;
        }
        if port0 & IoExpPort0::Sw4.bits() == 0 {
            println!("SW4 pressed");
            interaction_detected = true;
        }
        if port0 & IoExpPort0::Sw7Pos1.bits() != 0 {
            crswstate = Swstate::Top;
        }
        if port0 & IoExpPort0::Sw7Pos2.bits() != 0 {
            crswstate = Swstate::Bottom;
        }
        if crswstate != prswstate {
            prswstate = crswstate;
            interaction_detected = true;
        }
        if port2 & IoExpPort2::Sw6Pos1.bits() != 0 {
            clswstate = Swstate::Bottom;
        }
        if port2 & IoExpPort2::Sw6Pos2.bits() != 0 {
            clswstate = Swstate::Top;
        }
        if clswstate != plswstate {
            plswstate = clswstate;
            interaction_detected = true;
        }

        if sw5.is_low() {
            interaction_detected = true;
            println!("SW5 pressed");
        }

        if interaction_detected {
            SHARED_I2C.lock(|cell| {
                let mut i2c_ref = cell.borrow_mut();
                let i2c = i2c_ref.as_mut().unwrap();
                let (y, m, d, h, min, s) = read_rtc(i2c);
                println!(
                    "At time: {:04}-{:02}-{:02} {:02}:{:02}:{:02}",
                    y, m, d, h, min, s
                );
            });
            println!("Current Right Switch State: {:?}", crswstate);
            println!("Current Left Switch State: {:?}", clswstate);
            println!("Current LDR Reading Unavailable");
            println!("");
            // println!("");
        }

        Timer::after(Duration::from_millis(50)).await;
    }
}

#[embassy_executor::task]
async fn led_task(mut led1: Output<'static>) {
    let led_bits = IoExpPort2::Led2.or(IoExpPort2::Led3).bits();
    loop {
        // Turn on all LEDs
        led1.set_high();
        SHARED_I2C.lock(|cell| {
            let mut i2c_ref = cell.borrow_mut();
            let i2c = i2c_ref.as_mut().unwrap();
            let mut rbuf = [0u8];
            i2c.write_read(TCA6424_ADDR, &[OUT_PORT2], &mut rbuf)
                .unwrap();
            let current = rbuf[0];
            let new = current | led_bits;
            i2c.write(TCA6424_ADDR, &[OUT_PORT2, new]).unwrap();
        });
        Timer::after(Duration::from_secs(2)).await;

        // Turn off all LEDs
        led1.set_low();
        SHARED_I2C.lock(|cell| {
            let mut i2c_ref = cell.borrow_mut();
            let i2c = i2c_ref.as_mut().unwrap();
            let mut rbuf = [0u8];
            i2c.write_read(TCA6424_ADDR, &[OUT_PORT2], &mut rbuf)
                .unwrap();
            let current = rbuf[0];
            let new = current & !led_bits;
            i2c.write(TCA6424_ADDR, &[OUT_PORT2, new]).unwrap();
        });
        Timer::after(Duration::from_secs(2)).await;
    }
}

#[embassy_executor::task]
async fn sseg_task() {
    let segments = [
        IoExpPort1::SegA,
        IoExpPort1::SegB,
        IoExpPort1::SegC,
        IoExpPort1::SegD,
        IoExpPort1::SegE,
        IoExpPort1::SegF,
        IoExpPort1::Dp,
    ];

    // Set all digits on
    SHARED_I2C.lock(|cell| {
        let mut i2c_ref = cell.borrow_mut();
        let i2c = i2c_ref.as_mut().unwrap();
        let mut rbuf = [0u8];
        i2c.write_read(TCA6424_ADDR, &[OUT_PORT2], &mut rbuf)
            .unwrap();
        let current = rbuf[0];
        let digits = IoExpPort2::Digit1
            .or(IoExpPort2::Digit2)
            .or(IoExpPort2::Digit3)
            .or(IoExpPort2::Digit4)
            .bits();
        let new = current | digits;
        i2c.write(TCA6424_ADDR, &[OUT_PORT2, new]).unwrap();
    });

    loop {
        for &seg in segments.iter() {
            SHARED_I2C.lock(|cell| {
                let mut i2c_ref = cell.borrow_mut();
                let i2c = i2c_ref.as_mut().unwrap();
                i2c.write(TCA6424_ADDR, &[OUT_PORT1, !seg.bits()]).unwrap();
            });
            Timer::after(Duration::from_millis(300)).await;
            SHARED_I2C.lock(|cell| {
                let mut i2c_ref = cell.borrow_mut();
                let i2c = i2c_ref.as_mut().unwrap();
                i2c.write(TCA6424_ADDR, &[OUT_PORT1, 0xFF]).unwrap();
            });
        }

        // Cycle SegG separately
        SHARED_I2C.lock(|cell| {
            let mut i2c_ref = cell.borrow_mut();
            let i2c = i2c_ref.as_mut().unwrap();
            i2c.write(TCA6424_ADDR, &[OUT_PORT0, !IoExpPort0::SegG.bits()])
                .unwrap();
        });
        Timer::after(Duration::from_millis(300)).await;
        SHARED_I2C.lock(|cell| {
            let mut i2c_ref = cell.borrow_mut();
            let i2c = i2c_ref.as_mut().unwrap();
            i2c.write(TCA6424_ADDR, &[OUT_PORT0, 0xFF]).unwrap();
        });
    }
}

#[embassy_executor::task]
async fn buzzer_task(
    mut buzz_channel: channel::Channel<'static, LowSpeed>,
    mut timer: LedcTimer<'static, LowSpeed>,
) {
    timer
        .configure(timer::config::Config {
            duty: timer::config::Duty::Duty14Bit,
            clock_source: timer::LSClockSource::APBClk,
            frequency: Rate::from_hz(2700u32),
        })
        .unwrap();

    buzz_channel
        .configure(channel::config::Config {
            timer: &timer,
            duty_pct: 0,
            pin_config: channel::config::PinConfig::PushPull,
        })
        .unwrap();

    loop {
        buzz_channel.set_duty(50u8).unwrap();
        Timer::after(Duration::from_millis(500)).await;
        buzz_channel.set_duty(0u8).unwrap();
        Timer::after(Duration::from_millis(1500)).await;
    }
}

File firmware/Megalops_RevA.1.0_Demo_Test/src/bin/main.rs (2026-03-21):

#![no_std]
#![no_main]
#![deny(
    clippy::mem_forget,
    reason = "mem::forget is generally not safe to do with esp_hal types, especially those \
    holding buffers for the duration of a data transfer."
)]
#![deny(clippy::large_stack_frames)]

use embassy_executor::Spawner;
use embassy_time::{Duration, Timer};
use esp_backtrace as _;
use esp_hal::clock::CpuClock;
use esp_println::println;
use uferris_bsp::{SevenSegDigit, uferris_init};

extern crate alloc;

// This creates a default app-descriptor required by the esp-idf bootloader.
// For more information see: <https://docs.espressif.com/projects/esp-idf/en/stable/esp32/api-reference/system/app_image_format.html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>
esp_bootloader_esp_idf::esp_app_desc!();

#[allow(
    clippy::large_stack_frames,
    reason = "it's not unusual to allocate larger buffers etc. in main"
)]
#[esp_rtos::main]
async fn main(_spawner: Spawner) -> ! {
    let config = esp_hal::Config::default().with_cpu_clock(CpuClock::max());
    let peripherals = esp_hal::init(config);

    esp_alloc::heap_allocator!(#[esp_hal::ram(reclaimed)] size: 66320);

    let mut uferris = uferris_init(peripherals);

    // A Constant to Control the Speed of the test/Demo Loop
    const TEST_DELAY_MS: u64 = 200;

    // Set RTC to Known Time for Testing
    uferris.set_rtc_time(2026, 1, 29, 9, 16, 0).unwrap();

    loop {
        // ---------------------------------------
        // LED Tests
        // ---------------------------------------

        let datetime = uferris.read_rtc_time().unwrap();
        println!(
            "Commencing LED Testing at {:02}:{:02}:{:02} on {}/{}/{}",
            datetime.3, datetime.4, datetime.5, datetime.2, datetime.1, datetime.0
        );
        uferris.led1_on();
        Timer::after(Duration::from_millis(TEST_DELAY_MS)).await;

        uferris.led1_off();
        Timer::after(Duration::from_millis(TEST_DELAY_MS)).await;

        uferris.led2_on().unwrap();
        Timer::after(Duration::from_millis(TEST_DELAY_MS)).await;

        uferris.led2_off().unwrap();
        Timer::after(Duration::from_millis(TEST_DELAY_MS)).await;

        uferris.led3_on().unwrap();
        Timer::after(Duration::from_millis(TEST_DELAY_MS)).await;

        uferris.led3_off().unwrap();
        Timer::after(Duration::from_millis(TEST_DELAY_MS)).await;

        // ---------------------------------------
        // Seven Segment Tests
        // ---------------------------------------

        let datetime = uferris.read_rtc_time().unwrap();
        println!(
            "Commencing Seven Segment Testing at {:02}:{:02}:{:02} on {}/{}/{}",
            datetime.3, datetime.4, datetime.5, datetime.2, datetime.1, datetime.0
        );

        uferris
            .write_seven_segment_digit(SevenSegDigit::Digit1, Some(8))
            .unwrap();

        Timer::after(Duration::from_millis(TEST_DELAY_MS)).await;

        uferris
            .write_seven_segment_digit(SevenSegDigit::Digit1, None)
            .unwrap();

        Timer::after(Duration::from_millis(TEST_DELAY_MS)).await;

        uferris
            .write_seven_segment_digit(SevenSegDigit::Digit2, Some(8))
            .unwrap();

        Timer::after(Duration::from_millis(TEST_DELAY_MS)).await;

        uferris
            .write_seven_segment_digit(SevenSegDigit::Digit2, None)
            .unwrap();

        Timer::after(Duration::from_millis(TEST_DELAY_MS)).await;

        uferris.seven_segment_display_colon_en(true).unwrap();

        Timer::after(Duration::from_millis(TEST_DELAY_MS)).await;

        uferris.seven_segment_display_colon_en(false).unwrap();

        Timer::after(Duration::from_millis(TEST_DELAY_MS)).await;

        uferris
            .write_seven_segment_digit(SevenSegDigit::Digit3, Some(8))
            .unwrap();

        Timer::after(Duration::from_millis(TEST_DELAY_MS)).await;

        uferris
            .write_seven_segment_digit(SevenSegDigit::Digit3, None)
            .unwrap();

        Timer::after(Duration::from_millis(TEST_DELAY_MS)).await;

        uferris
            .write_seven_segment_digit(SevenSegDigit::Digit4, Some(8))
            .unwrap();

        Timer::after(Duration::from_millis(TEST_DELAY_MS)).await;

        uferris
            .write_seven_segment_digit(SevenSegDigit::Digit4, None)
            .unwrap();

        // ---------------------------------------
        // Buzzer Test
        // ---------------------------------------

        let datetime = uferris.rtc.read_time().unwrap();
        println!(
            "Commencing Buzzer Testing at {}:{}:{} on {}/{}/{}",
            datetime.2, datetime.1, datetime.0, datetime.5, datetime.4, datetime.3
        );

        Timer::after(Duration::from_millis(TEST_DELAY_MS)).await;

        uferris.buzz_on(1024);

        Timer::after(Duration::from_millis(2000)).await;

        uferris.buzz_off();

        // ---------------------------------------
        // LDR Testing
        // ---------------------------------------

        let datetime = uferris.read_rtc_time().unwrap();
        println!(
            "Commencing LDR Testing at {:02}:{:02}:{:02} on {}/{}/{}",
            datetime.3, datetime.4, datetime.5, datetime.2, datetime.1, datetime.0
        );
        println!("Taking Three Readings with 3s Delay Between Readings");
        let ldr_value = uferris.read_ldr();
        println!("First LDR Reading: {}", ldr_value);
        println!("Waiting 3 Seconds...");
        Timer::after(Duration::from_millis(3000)).await;
        let ldr_value = uferris.read_ldr();
        println!("Second LDR Reading: {}", ldr_value);
        println!("Waiting 3 Seconds...");
        Timer::after(Duration::from_millis(3000)).await;
        let ldr_value = uferris.read_ldr();
        println!("Third LDR Reading: {}", ldr_value);
        println!("LDR Reading Test Complete.");

        // ---------------------------------------
        // Button Press Tests
        // ---------------------------------------

        let datetime = uferris.read_rtc_time().unwrap();
        println!(
            "Commencing Button Press Testing at {:02}:{:02}:{:02} on {}/{}/{}",
            datetime.3, datetime.4, datetime.5, datetime.2, datetime.1, datetime.0
        );
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

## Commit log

2026-01-11 Rev A.0.3 Initial Commit
    [BOM_uFerris Megalops Baseboard_Megalops PCB_2026-01-11.csv, BOM_uFerris Megalops Baseboard_Megalops Schematic_2025-11-02.csv, BOM_uFerris Megalops Powerboard_P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]
2026-02-16 RevA.0.4 Updates
    [3D_Megalops PCB_2026-01-11.step, 3D_Megalops PCB_2026-02-16.step, 3D_Powerboard PCB_2026-01-11.step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]
2026-04-07 RevA.1.0
    RevA.1.0 Hardware Files
    [3D_Megalops PCB_2026-02-16.step, 3D_Megalops PCB_2026-04-07.step, 3D_Powerboard PCB_2026-02-16.step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]
2026-06-02 Fix notes and update RISC-V target in getting-started.md
    Correct note formatting and update RISC-V target reference for ESP32-C3.
2026-06-02 Update note on USB-C power and battery interaction
    Clarified note regarding USB-C power and battery usage.
2026-06-16 RevA.1.1 Update
    [3D_Megalops PCB_2026-04-07.step, 3D_Powerboard PCB_2026-04-07.step, BOM_uFerris Megalops Baseboard_Megalops PCB_2026-06-16.csv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]
2026-10-07 BB RevA.2.0 & TB RevA.0.0
    [BOM_uFerris Megalops Baseboard_Megalops PCB_2026-06-16.csv, BOM_uFerris Megalops Baseboard_Megalops PCB_2026-10-07.csv, BOM_uFerris Megalops Telemetry_Telemetr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]
2026-10-07 Pin Map
    [uFerrisPinMapping.xlsx]
